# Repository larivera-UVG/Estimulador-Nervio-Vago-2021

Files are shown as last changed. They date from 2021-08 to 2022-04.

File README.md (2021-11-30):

# Estimulador-Nervio-Vago-2021
Desarrollo de un módulo de estimulación para el nervio vago, y su varilla de programación. En este repositorio se encuentran la combinacion de todos los avances logrados en la Fase III del desarollo de un prototipo de estimulador de nervio vago de la Universidad del Valle de Guatemala. Los aportes estan basados en el trabajo de las fases pasadas del proyecto. En esta fase se logro establecer la comunicacion inalambrica de los dos modulos que conforman el estimulador VNS. Ademas se hicieron estudios para determinar el material de desarollo para la carcasa del modulo estimulador, asi como un estudio para validar los parametros de descarga del mismo. Asi mismo se hicieron mejoras a ambos modulos por medio de diseno 3D y diseno de circuitos impresos. 
## Modulo Estimulador
Este es el primero de los dos modulos que conforman el sistema de estimualcion VNS. Este modulo es el encargado de generar la estimulacion electrica responsable de administrar el tratamiento. Es un modulo de 3cm de diametro, conformado completamente por componentes SMD a medida de reducir su tamano.
### Funcionamiento
El modulo estimulador es un circuito digital que consiste de 3 partes clave. Primero se tiene como microcontrolador un ATSAMD21E18-MU para ser usado y programado como un _Trinket M0_. Luego tenemos tenemos un regulador de voltaje que convierte la entrada de 5 V a una salida de 3.3 V. Luego se tiene un convertidor de voltaje a corriente XTR 111 que se encarga de tomar la senal PWM que producida por el ATSAMD21E18, y transforma los pulsos de voltaje a su equivalente en corriente por medio de un espejo de corriente que utiliza de manera externa un circuito con un MOSFET para regular la salida. Para poder alimentar la fuente de corriete que se genera apartir del convertidor de voltaje a corriente se tiene un circuito elevador de voltaje por medio de un LM2622 que opera a 600 kHz. Este provee la alimentacion de 7 volts que es necesaria para activar el convertidor de voltaje a corriente. or ultimo se tiene un Mini-NRF24L01 que se encarga de recibir los parametros de estimulacion enviador por medio de la varilla programadora.
### Codigos
Los codigos utilizados para el modulo estimulador se dividen en 2 partes. Una serie de codigos para pruebas directamente con los breakout boards (Trinket M0) y los modulos de comunicacion RF (NRF24L01). Los demas codigos son los codigos encargados de generar los pulsos PWM con una rampa de inicio y una rampa de bajada desarollados por Gustavo Ordoñez, en conjunto con la seccion de codigo encargada de generar la comunicacion por medio de RF por medio de la funcion __RFBegin__ y la funcion __RFSetup__.
#### Codigos Para Pruebas de Comunicacion
De los codigos para pruebas se tienen los siguientes archivos:
* Codigos_de_Diagnostico_para_los_modulos: Este codigo imprime en la consola (COM) los parametros de transmision del modulo NRF24L01 e indica si este tiene problemas de transmision:
* Pruebas basicas de diagnostico:
  * Trinket_reciver: Esta es un prueba donde el ESP8266/ESP Wroom32 mandan una serie de caracteres y en este codigo el trinket recibe los caracteres y los muestra en la interfaz serial
  * SAMD_a_ESP8266_nRF24L01: Este es una version con mas modos de prueba que el codigo anterior. Por medio de 5 _cases_ se puede probar mandar, recibir, mandar y rebir datos de el trinket a otro microcontrolador con el modulo nEF24L01 y los _addresses_ indicados
  * Slave_NRF_tester: Un codigo que prueba mandar una serie de numeros que incrementan de manera lineal. Aqui el receptor no reporta nada, solo el emisor reporta si el envio fue exitoso o no
  * Pruebas_con_el_ESP32: Codigo de pruebas para ver si se podian recibir los datos desde el ESP Wroom 32
#### Codigo del modulo estimulador
Aqui solo se tiene un archivo de codigo comentado que es la combinacion del codigo de Gustavo y mi codigo. Este es el codigo que se le debe de cargar al modulo estimulador para poder lograr la comunicacion RF y la generacion de Pulsos
* PWM_Module_With_RF
### Modelos CAD
*De momento todavia no hay archivos cad para la carcaza del estimulador*
#### Archivos de Inventor 2021
Para poder acesar a los archivos de inventor en conjunto con las librerias de componentes, dadas las limitaciones de tamano de 100 MB para un repositorio de Github, estas se van a colocar como un archivo de texto (.txt) que contiene el link al Google Drive donde estan subidos y distribuidos por carpetas
Tambien adjunto el link aqui: 
#### STLs
Los archivos que se obtienen apartir del programa CAD, en este caso Inventor 2021, para ser introducidos al _slicer_ (software encargado de traducir el STL a codigo que puede ser interpretado por la impresora) que en torno genera G-code. Se recomendaria utilizar estos archivos para impresion de la carcasa, ya que al utilizar directamtente el G-code, puede que este no este optimizado para impresora donde se quiere imprimir.
#### G-Code
El G-Code fue generado utilizando el _slicer_ de Ultimaker, Ultimaker Cura Version 4.7. Se optimizo para poderse imprimir con una Ender 3 V1 y utilizando filamento PLA+. Es importante notar que la temperatura de impresion del PLA+ es superior a la del PLA normal. Tambien se optimizaron los comandos para reducir el _stringing_ y otros fenomenos del filamento. Se hiceron impresiones con PLA+ azul oscuro de eSUN y PLA+ cobre _silky_ tambien de eSUN. Los resultados de impresion con otros filamentos y en otras impresoras pueden ser diferentes. Sin embargo, las impresiones estan siempre puestas en el centro de la cama de impresion. La ender 3 V2 tiene un volumen de impresion de 25x25x30 cm.
### Pruebas de Neuro Estimulacion
#### Archivo de LTspice
Este archivo contiene los circuitos con los parametros de simulacion adecuados para validar los resultados teoricos
* Simulacion Nervio Vago.asc: Archivo para ser abierto en LTspice con los circuitos y parametros
* Simulacion Nervio Vago.raw: Archivo que contiene los parametros para replicar las graficas
* Simulacion Nervio Vago.plt
* Simulacion Nervio Vago.log
## Modulo Programador
### Codigos
Los codigos utilizados para la varilla programadora se dividen en 3 partes. Al igual que el modulo estimulador se tienen codigos para pruebas de comunicacion por medio del modulo NRF24L01. Luego se tiene el codigo principal que le da funcionalidad WiFi y RF a la varilla programadora. Por ultimo esta el codigo de la interfaz grafica que le deja al usuario programar los parametros por medio de una consola corriendo una aplicacion de Python.
### Codigo de la varilla programadora
* Compu_a_Esp_a_SAMD21: Este codigo
### Codigo para la interfaz grafica
* Interfaz_VNS.py
### Codigo para pruebas de comunicacion
* Codigos de Diagnostico
 * I2C_Scanner: Da la direccion de cualquier dispositivo conectado por medio de I2C a el ESP8266
 * lcd_i2c-test: Pruebas para verificar que los datos mandados por I2C aparezcan en la pantalla LCD 1602
 * Master_NRF_Tester: Codigo hermano del Slave_NRF_tester que muestra en la pantalla serial si se estan recibiendo exitosamente una serie de numeros incrementales, si no es el caso avisa que hubo un error de comunicacion de la forma "TX Failed"
*  ESP8266_a_SAMD21_nRF4L01: Codigo hermano de SAMD_a_ESP8266_nRF24L01 que se utiliza para hacer pruebas de emision, recepcion, emision y recepcion e inclusive pruebas de la pantalla LCD por medio de I2C para el ESP8266 y el ESP Wroom32
*  Trinket_Como_Receptor_de_los_Parametros: Codigo de Pruebas basicas para recibir datos en forma de un array desde el Arduino o desde el ESP8266
### Modelos CAD 
Misma descripcion que para el modulo estimulador, pero se van a dar dos links diferentes a la misma carpeta de Google Drive para facilitar el orden.
#### Archivos de Inventor 2021
Para poder acesar a los archivos de inventor en conjunto con las librerias de componentes, dadas las limitaciones de tamano de 100 MB para un repositorio de Github, estas se van a colocar como un archivo de texto (.txt) que contiene el link al Google Drive donde estan subidos y distribuidos por carpetas
Tambien adjunto el link aqui: 
#### STLs
Los archivos que se obtienen apartir del programa CAD, en este caso Inventor 2021, para ser introducidos al _slicer_ (software encargado de traducir el STL a codigo que puede ser interpretado por la impresora) que en torno genera G-code. Se recomendaria utilizar estos archivos para impresion de la carcasa, ya que al utilizar directamtente el G-code, puede que este no este optimizado para impresora donde se quiere imprimir.
#### G-Code
El G-Code fue generado utilizando el _slicer_ de Ultimaker, Ultimaker Cura Version 4.7. Se optimizo para poderse imprimir con una Ender 3 V1 y utilizando filamento PLA+. Es importante notar que la temperatura de impresion del PLA+ es superior a la del PLA normal. Tambien se optimizaron los comandos para reducir el _stringing_ y otros fenomenos del filamento. Se hiceron impresiones con PLA+ azul oscuro de eSUN y PLA+ cobre _silky_ tambien de eSUN. Los resultados de impresion con otros filamentos y en otras impresoras pueden ser diferentes. Sin embargo, las impresiones estan siempre puestas en el centro de la cama de impresion. La ender 3 V2 tiene un volumen de impresion de 25x25x30 cm.
## Open OCD
En esta carpeta estan tanto los archivos de Altium asi como los Gerbers necesarios para la fabricacion de la placa que se uso para cargar el _bootloader_ al SAMD21E18-AF. 
Se utilizaron los siguientes links para poder cargar OpenOCD en una Rapberry Pi 3B+ y generar el archivo .hex que contiene el bootloader del arduino zero y el uf2 para el trinket M0:
* [Link para adaptar un Trinket M0 a un Nintendo Switch](http://www.google.fr/ "Named link title")
* [Video de como instalar OpenOCD en la RaspberryPi y cargar el archivo .hex](http://www.google.fr/ "Named link title")
* [Tutorial de Adafruit de como usar OpenOcd](http://www.google.fr/ "Named link title")
## Estudio de Mercado para La bio-compatibilidad
Este estudio esta presentado en un archivo de Microsoft Excel .xlxs y tiene diversas partes. Una parte del estudio encuadra el listado de los 8 materiales y por medio de tres fuentes de lugares diferentes (locales de ser posible) determina el precio/g del material. Otra parte esta donde se indican las caracteristicas a ser comparadas a mayor detalle. Tambien hay un recuadro donde se catalogan las propiedades mecanicas relevantes a la ergonomia y fabricacion de los materiales. Otra seccion explica los criterios de biocompatibilidad y explica porque se determino que el material tenia que ser bio-inerte. Por ultimo se tiene el recuadro donde se ejemplifica el estudio de mercado con los resultados para cada material
## Documentacion
### Excel con el resumen de todas las corridas de las pruebas de simulacion de nervio vago
Este archivo contiene la compilacion de las diferentes corridas con las medidas en los nodos mas importantes. Se tienen 4 paginas, una para la corrida de un solo nodo (extension de 1cm de tejido) y la otra con 5 nodos (extension de 6 cm de tejido) ademas de una pagina donde se realizaron pruebas transitorias y otra donde se deriva el despeje matematico del circuito

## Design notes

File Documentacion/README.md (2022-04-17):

# Documentacion
## Detalles:
En la documentacion se encuentran los archivos y articulos relevantes que se pueden utulizar para derivar los resultados a los que se llegaron en la tesis , en la documentacion contamos con los siguientes archivos:
### 2.1 Trade_Studies_Module...
Este archivo contiene la metodologia de space systems engineering de la NASA para desarollar un Estudio de Mercado como el que utilizo en la investigacion de bio-compatibilidad
### Articulo Cientifico Rodrigo Figueroa
Este documento contiene el articulo cientifico donde se detalla de manera breve los avances en el desarollo del sistema de intercomunicaicon y los dos estudios, el de biocompatibilidad y el estudio del modelo del nervio vago

### Copia de Presentacion de....
Este archivo contiene la presentacion en formato PDF que se utilizo en la defensa de terna de esta tesis

### Guia_para_La_instalacion:
Es un documento corto que detalla los pasos necesarios para poder descargadr todas las librerias necesarias para correr el dispositivo.

### Protocolo_2021_Rodrigo...
Aqui esta el protocolo presentado en la primera mitad del ano 2021 que detallaba los pasos a seguir en el desarollo de la tesis
### Pruebas Teoricas de descarga....
Este documento .xl contiene el documento donde se detallan los resultados de las pruebas de simulacion realizados atraves de LTSpice para validar el modelo del nervio vago

### Tesis_2021__Rodrigo...
Este documento contiene la version de la tesis que se presento a finales de Diciembre de 2021 sin ser editado por el comite de estilo y redaccion de la UVG

### Trade Study-Biomateriales: 
Este documento contiene los resultados del estudio de biocompatibilidad que se explican en la tesis.

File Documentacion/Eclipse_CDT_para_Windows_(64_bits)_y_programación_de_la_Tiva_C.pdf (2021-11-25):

Universidad Del Valle de Guatemala
Departamento de Ingeniería Electrónica, Mecatrónica y Biomédica
Luis Alberto Rivera

## Instalación de Eclipse CDT, GNU ARM Embedded Toolchain y TivaWare C para Windows 10 (64 bits)

Desarrollo de Programas para la Tiva C

Eclipse y MinGW

La instalación de Eclipse y MinGW se ilustra en el siguiente vídeo. Abajo se dan los enlaces para descargar los paquetes y se dan instrucciones adicionales. https://www.youtube.com/watch?v=WRYHKNVV5H0

Instalador de Eclipse (eclipse-inst-win64.exe): https://www.eclipse.org/downloads/packages/installer
Nota: Correr el ejecutable puede tardar un poco.
Aparecerá una ventana para seleccionar el IDE específico que desea. Seleccione el “Eclipse IDE for C/C++ Developers”.

Instalar GCC (MinGW64): Esto permite compilar programas en C/C++ para Windows.
Descargue el ejecutable | MinGW-W64-install.exe (https://sourceforge.net/projects/mingw-w64/files/Toolchains%20targetting%20Win32/Personal%20Builds/mingw-builds/installer/mingw-w64-install.exe) | (no el .zip) de
https://sourceforge.net/projects/mingw-w64/files/mingw-w64/
Al correr el instalador, en la ventana de Settings, posiblemente necesite cambiar la opción de “Architecture” a x86_64. Vea el vídeo indicado arriba (minuto 6:14). En la opción de versión, deje la versión más reciente.

Agregar gcc/g++ de MinGW al “System Path”: Esto es para que Eclipse detecte a MinGW GCC automáticamente, y para poder compilar directamente desde una terminal fuera de Eclipse.
Siga las instrucciones de la página web siguiente, a partir del paso #12: http://www.codebind.com/cprogramming/install-mingw-windows-10-gcc/

Nota: Probablemente la ruta que deba agregar sea distinta a la mostrada en la página web anterior. Allí se muestra “C:\MinGW\bin”, pero es probable que la ruta sea algo como “C:\Program Files\mingw-w64\x86_64-8.1.0-posix-seh-rt_v6-rev0\mingw64\bin”.

En la figura siguiente se muestra la ventana en la que debe agregar la ruta. Note que puede buscar el respectivo folder con el botón “Browse…”.

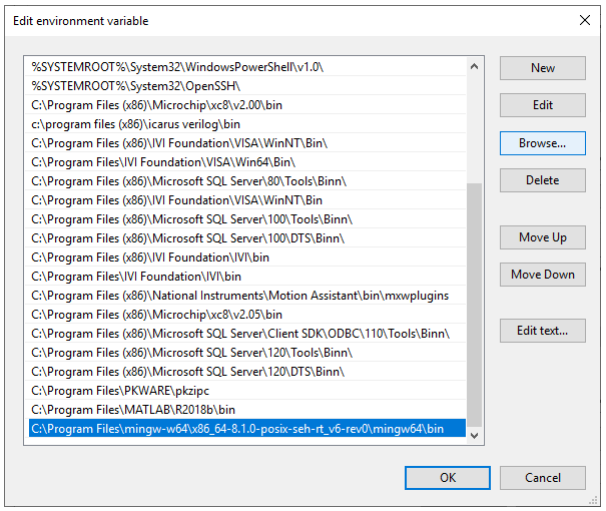
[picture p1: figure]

Para verificar que todo está bien, pruebe crear un programa “Hello World”, compilarlo y correrlo en Eclipse. Luego, pruebe correr el programa compilado en Eclipse en una terminal externa a Eclipse (Command Prompt y/o Windows PowerShell). Finalmente, pruebe compilar el programa directamente desde la terminal externa usando gcc. Corra el programa. Todo esto se ilustra en el documento “Eclipse Hello World.pdf”.

LM Flash Programmer, TivaWare C y GNU ARM Embedded Toolchain

Descargue e instale el LM Flash Programmer (LMFlashProgrammer.msi): http://www.ti.com/tool/LMFLASHPROGRAMMER
Necesitará registrarse. El usuario creado de Texas Instruments le servirá para éste y otros productos.

Descargue e instale el TivaWare C para los controladores de la serie TM4C (SW-TM4C-2.1.4.178.exe):
http://software-dl.ti.com/tiva-c/SW-TM4C/latest/index_FDS.html
Puede ingresar con el mismo usuario creado anteriormente.

Instale el GNU ARM Embedded Toolchain (arm-none-eabi):
(descargue el .exe de la versión más reciente para Windows; no importa que diga 32 bits) https://developer.arm.com/tools-and-software/open-source-software/developer-tools/gnu-toolchain/gnu-rm/downloads (https://developer.arm.com/tools-and-software/open-source-software/developer-tools/gnu-toolchain/gnu-rm/downloads)

IMPORTANTE: Antes de terminar la instalación, marque la casilla “Add path to environment variable”, si ésta no está marcada por defecto.

Al parecer, en C:\Program Files (x86)\GNU Tools Arm Embedded\9 2019-q4-major\bin no está el ejecutable make.exe, necesario a la hora de compilar. Se puede usar el make.exe que trae MinGW64. Siga los siguientes pasos:

Vaya a: C:\Program Files\mingw-w64\x86_64-8.1.0-posix-seh-rt_v6-rev0\mingw64\bin Debería ver el ejecutable “mingw32-make.exe”. Copie dicho archivo al directorio C:\Program Files (x86)\GNU Tools Arm Embedded\9 2019-q4-major\bin
Finalmente, cámbiele el nombre de “mingw32-make.exe” a “make.exe”.

Nota: las rutas indicadas arriba se asumen por defecto. Éstas pueden diferir, según su instalación de GNU ARM Embedded Toolchain y MinGW.

Desarrollo de Programas para la Tiva C en Eclipse:

Abra Eclipse y seleccione el workspace en que se desee trabajar.

Cree un proyecto nuevo: en el menú principal, File > New > C/C+ Project. En la ventana que aparece, seleccione la opción “C Managed Build”.

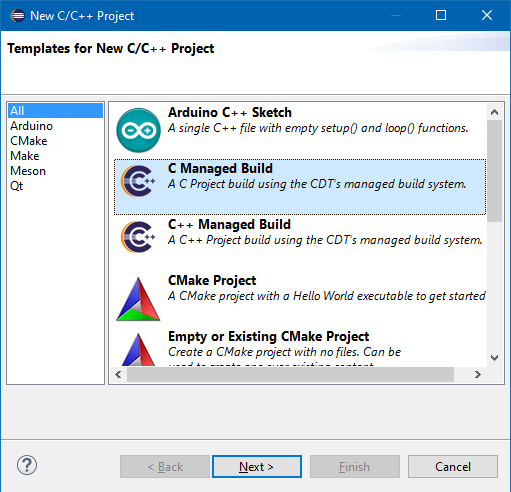
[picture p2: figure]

Seleccione el tipo de proyecto “Empty Project” y el toolchain “Cross GCC”. Dé un nombre al proyecto en el espacio correspondiente.

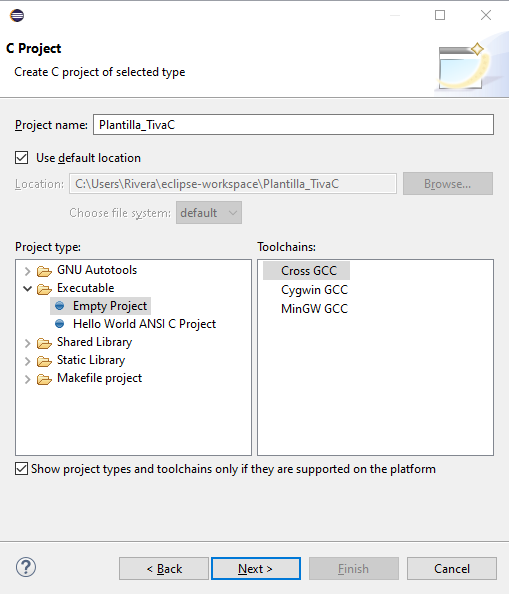
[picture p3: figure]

En la ventana “Select Configurations”, remueva el cheque en el cuadro “Debug”, dejando únicamente la opción de “Release”. Dele click en “Finish”.
Nota 1: se pueden dejar las dos opciones, pero se deberá tener mucho cuidado para las configuraciones que se describen más adelante. También se puede dejar únicamente la opción “Debug”, si se desea usar el debugger de Eclipse.
Nota 2: En “Advanced settings” se pueden hacer las configuraciones que se describen a continuación, de una vez. Dichas configuraciones se pueden hacer después de crear el proyecto, como se explica abajo.

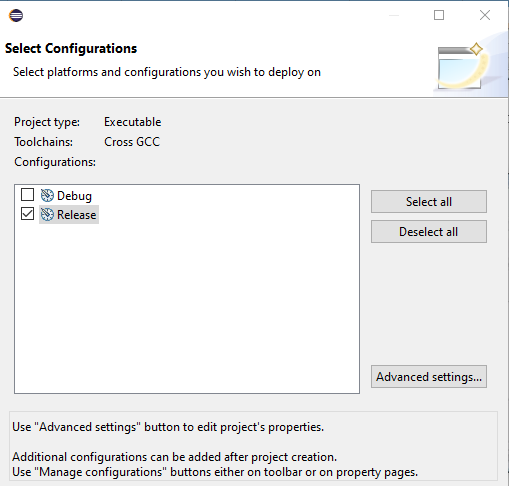
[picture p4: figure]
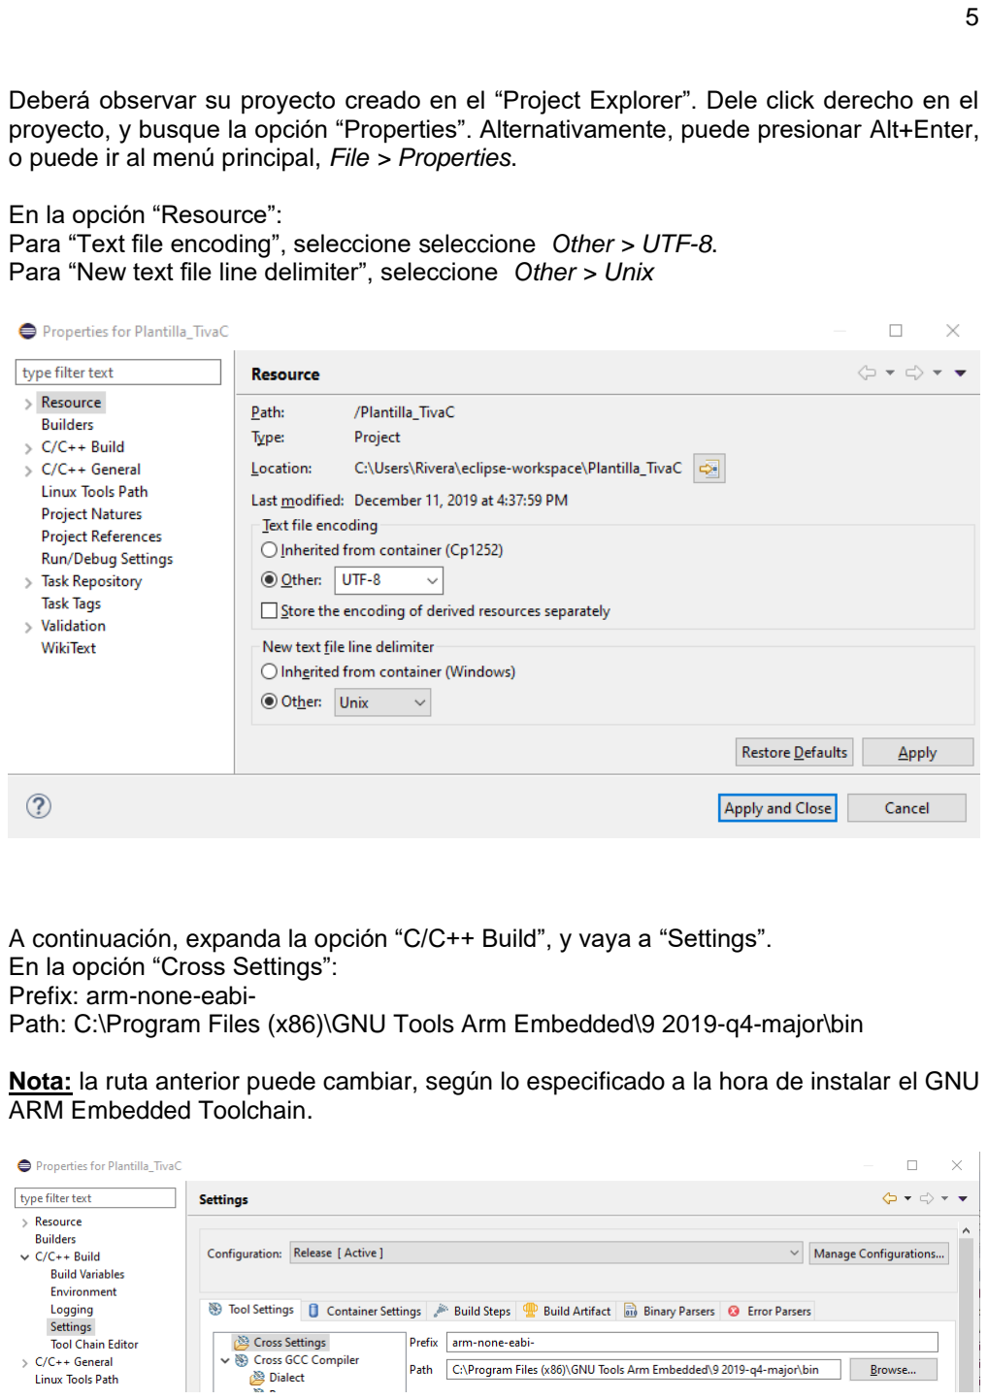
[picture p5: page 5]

Deberá observar su proyecto creado en el “Project Explorer”. Dele click derecho en el proyecto, y busque la opción “Properties”. Alternativamente, puede presionar Alt+Enter, o puede ir al menú principal, File > Properties.

En la opción “Resource”:
Para “Text file encoding”, seleccione seleccione Other > UTF-8.
Para “New text file line delimiter”, seleccione Other > Unix

A continuación, expanda la opción “C/C++ Build”, y vaya a “Settings”.
En la opción “Cross Settings”:
Prefix: arm-none-eabi-Path: C:\Program Files (x86)\GNU Tools Arm Embedded\9 2019-q4-major\bin

Nota: la ruta anterior puede cambiar, según lo especificado a la hora de instalar el GNU ARM Embedded Toolchain.

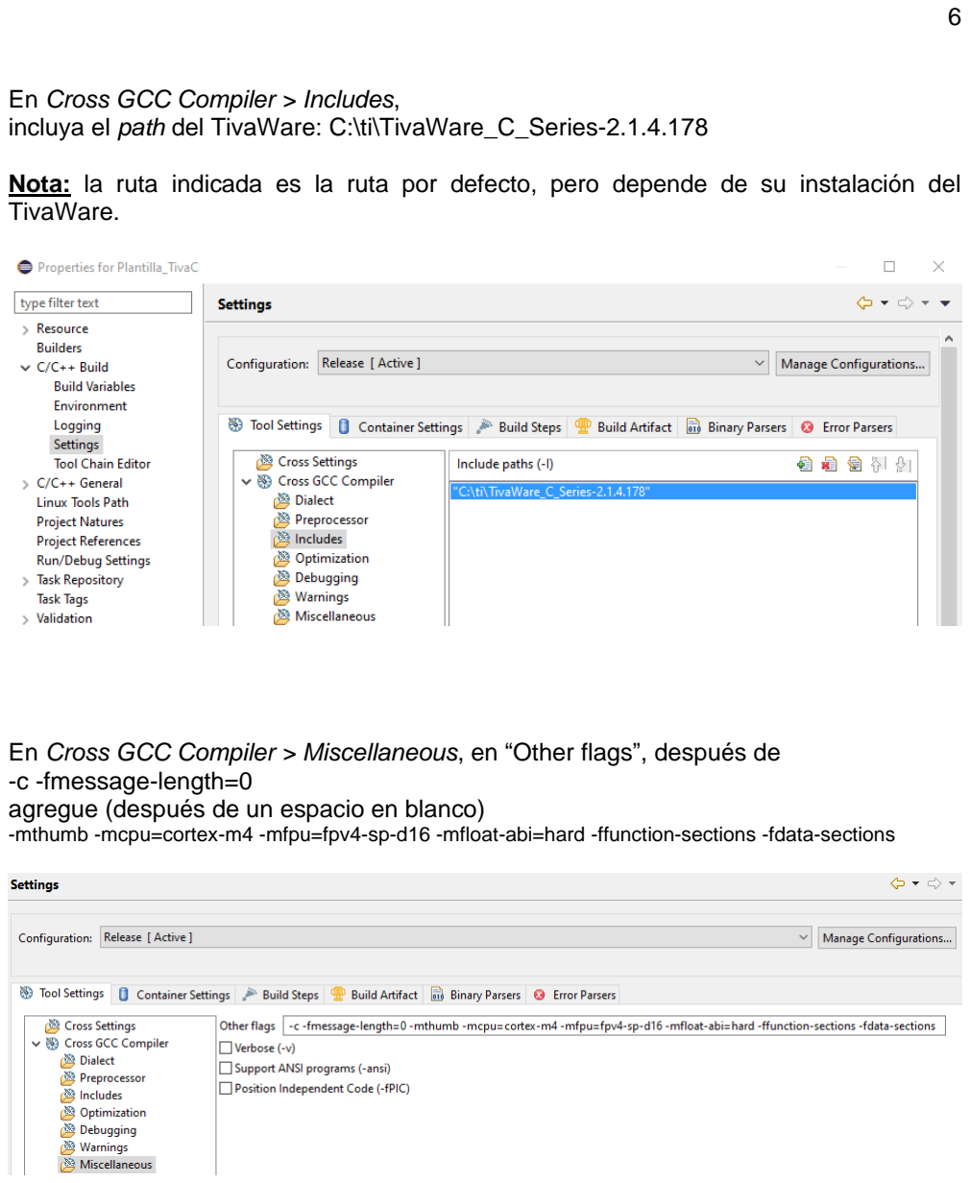
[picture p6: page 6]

En Cross GCC Compiler > Includes,
incluya el path del TivaWare: C:\ti\TivaWare_C_Series-2.1.4.178

Nota: la ruta indicada es la ruta por defecto, pero depende de su instalación del TivaWare.

En Cross GCC Compiler > Miscellaneous, en “Other flags”, después de
-c -fmessage-length=0
agregue (después de un espacio en blanco)
-mthumb -mcpu=cortex-m4 -mfpu=fpv4-sp-d16 -mfloat-abi=hard -ffunction-sections -fdata-sections

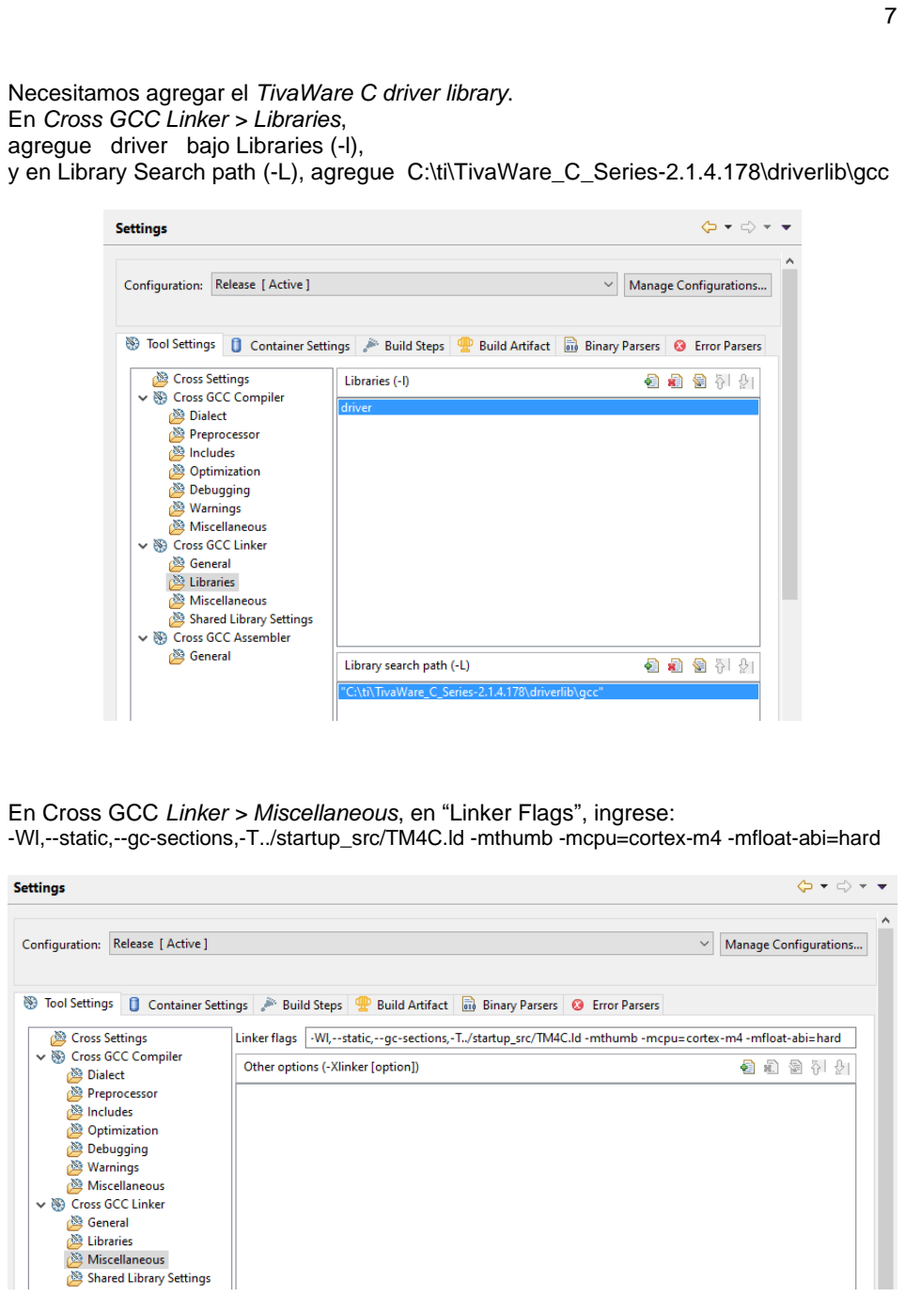
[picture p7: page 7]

Necesitamos agregar el TivaWare C driver library.
En Cross GCC Linker > Libraries,
agregue driver bajo Libraries (-l),
y en Library Search path (-L), agregue C:\ti\TivaWare_C_Series-2.1.4.178\driverlib\gcc

En Cross GCC Linker > Miscellaneous, en “Linker Flags”, ingrese: -Wl,--static,--gc-sections,-T../startup_src/TM4C.ld -mthumb -mcpu=cortex-m4 -mfloat-abi=hard

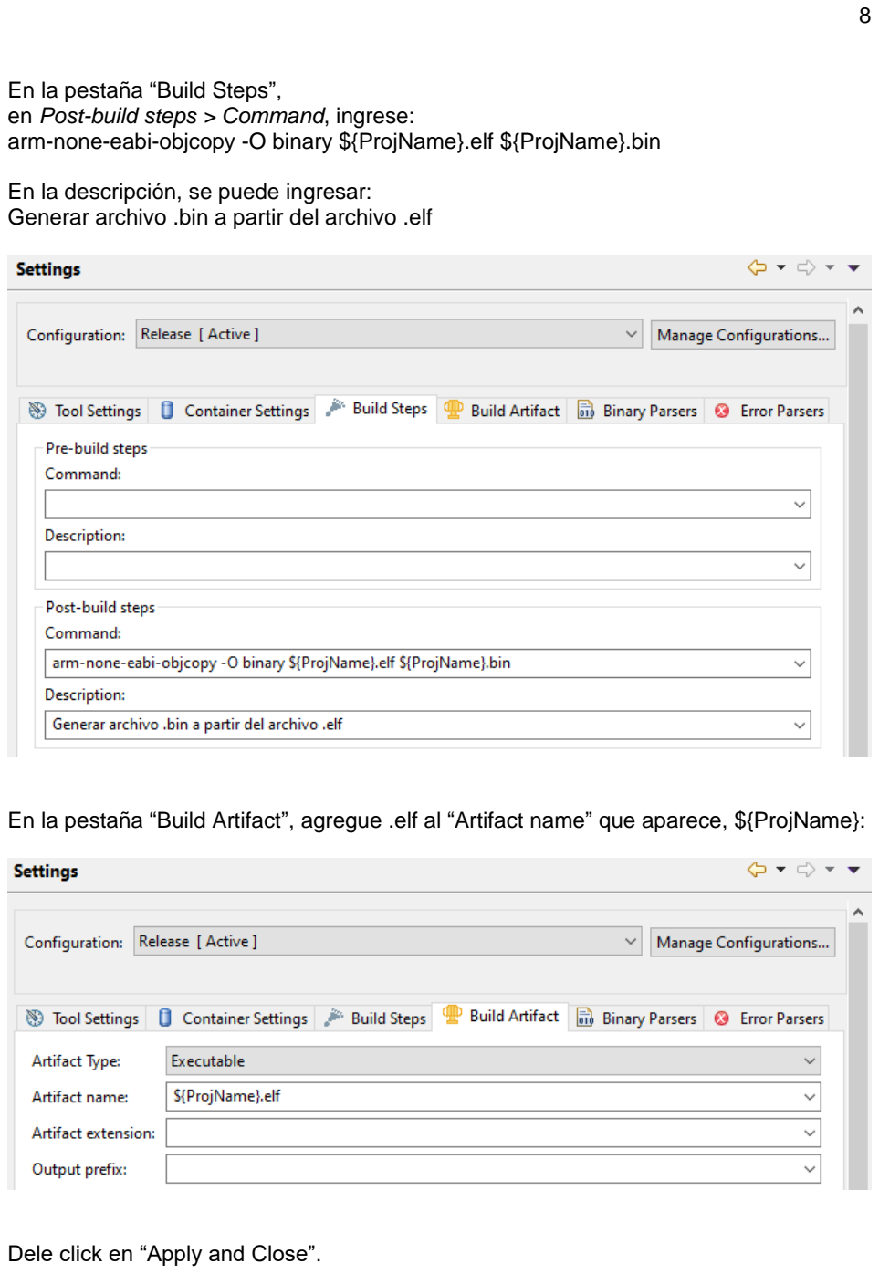
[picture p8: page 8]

En la pestaña “Build Steps”,
en Post-build steps > Command, ingrese:
arm-none-eabi-objcopy -O binary ${ProjName}.elf ${ProjName}.bin

En la descripción, se puede ingresar:
Generar archivo .bin a partir del archivo .elf

En la pestaña “Build Artifact”, agregue .elf al “Artifact name” que aparece, ${ProjName}:

Dele click en “Apply and Close”.

Ahora necesitamos agregar archivos fuente al proyecto.
En primer lugar, descargue el folder “startup_src” que se encuentre en Canvas. Copie el folder “startup_src” al folder de su proyecto en el “Project Explorer” de Eclipse. “startup_src” tiene dos archivos, TM4C_startup.c, y TM4C.ld, los cuales tienen definiciones y declaraciones necesarias para inicializar su programa.

Finalmente, se debe agregar el archivo con su programa. Como ejemplo, copie el archivo blinky.c (también en Canvas). Este programa configura un LED de la Tiva C y lo enciende y apaga constantemente.

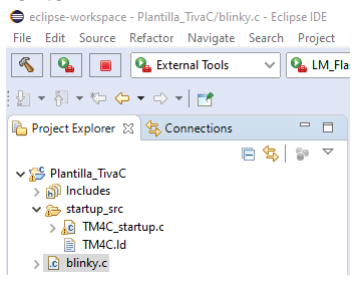
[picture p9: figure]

Con todo lo anterior, ya está listo para compilar su programa. Para compilar, busque el ícono de build (un martillo). Alternativamente, puede ir al menú principal y buscar Project > Build Project.
Si todo está bien, al compilar no aparecerán mensajes de error en la consola, y en el folder de su proyecto aparecerá el folder “Release” (y/o “Debug”, según la configuración de su proyecto). En “Release”, verá varios archivos, incluido un .bin. El archivo .bin es el que se cargará a la Tiva C, como se explica más adelante.

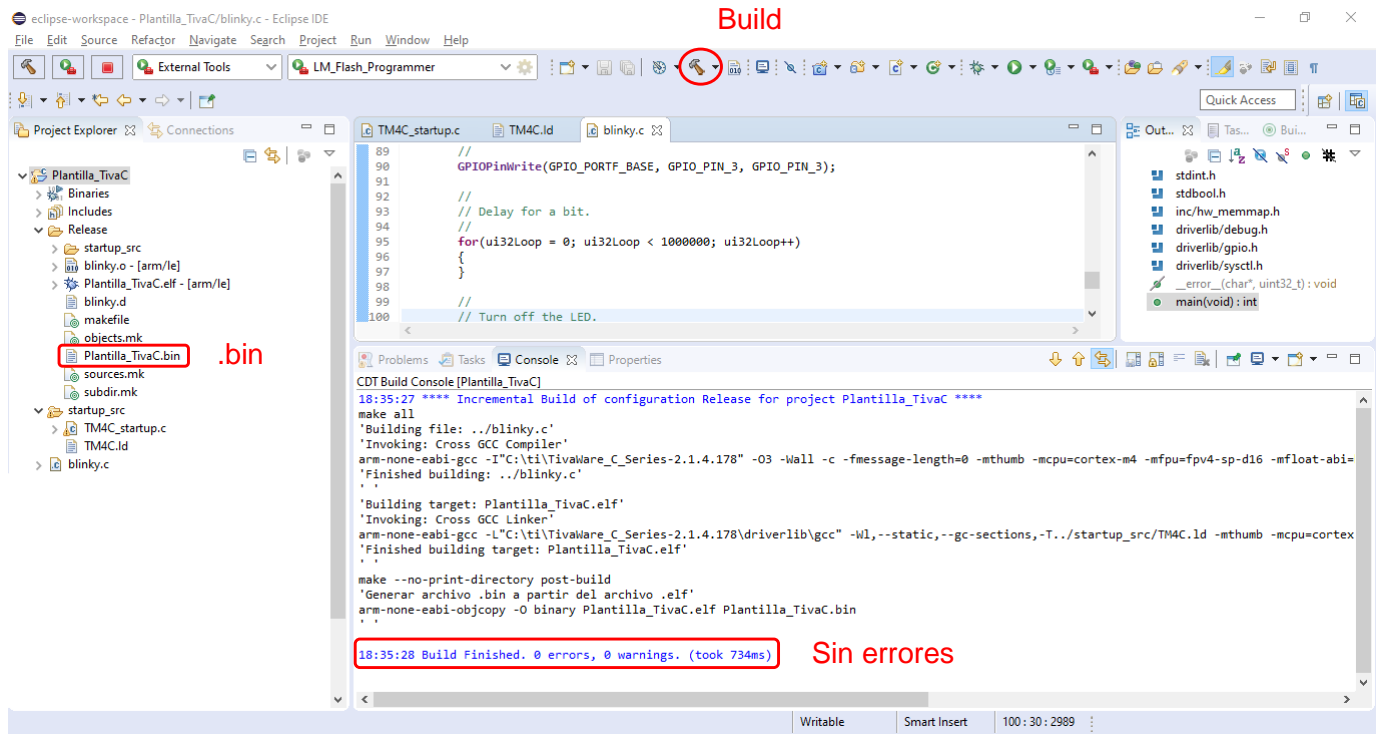
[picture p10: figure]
Build; .bin; Sin errores

Para futuros programas, puede crear proyectos en blanco e importar archivos y configuraciones desde el proyecto anterior. Así, sólo deberá reemplazar/agregar los archivos .c. No necesitará hacer todas las configuraciones nuevamente.

Para programar la Tiva C

Usando LM Flash Programmer directamente
Abra el programa.
En la pestaña “Program”, busque el archivo .bin generado en Eclipse. Se recomienda seleccionar la opción “Reset MCU After Program” (si no, deberá presionar el botón de Reset de la Tiva luego de programar, para que el programa empiece a ejecutar).
Dele click en el botón “Program”.

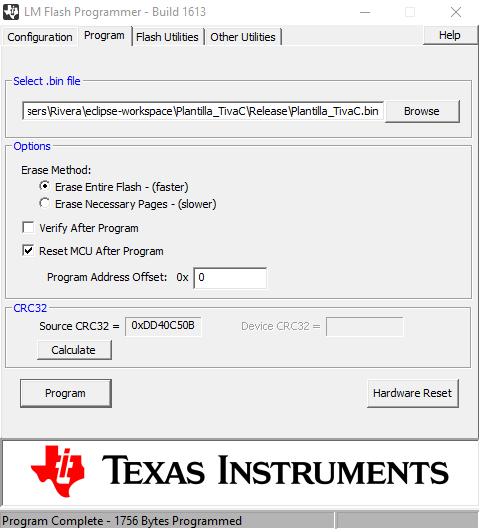
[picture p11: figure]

Usando LM Flash Programmer desde Eclipse
Vaya al menú de Eclipse en la parte superior. Busque Run > External Tools > External Tools Configurations.
Dele click en “New launch configuration”
Nombre la configuración (se sugiere LM_Flash_Programmer)
Busque la ubicación del LMFlash.exe y colóquela en “Location”.
En “Working Directory”, busque el directorio donde se encuentra el archivo .bin que se desea quemar en la Tiva.
En “Arguments”, coloque: ${project_name}.bin

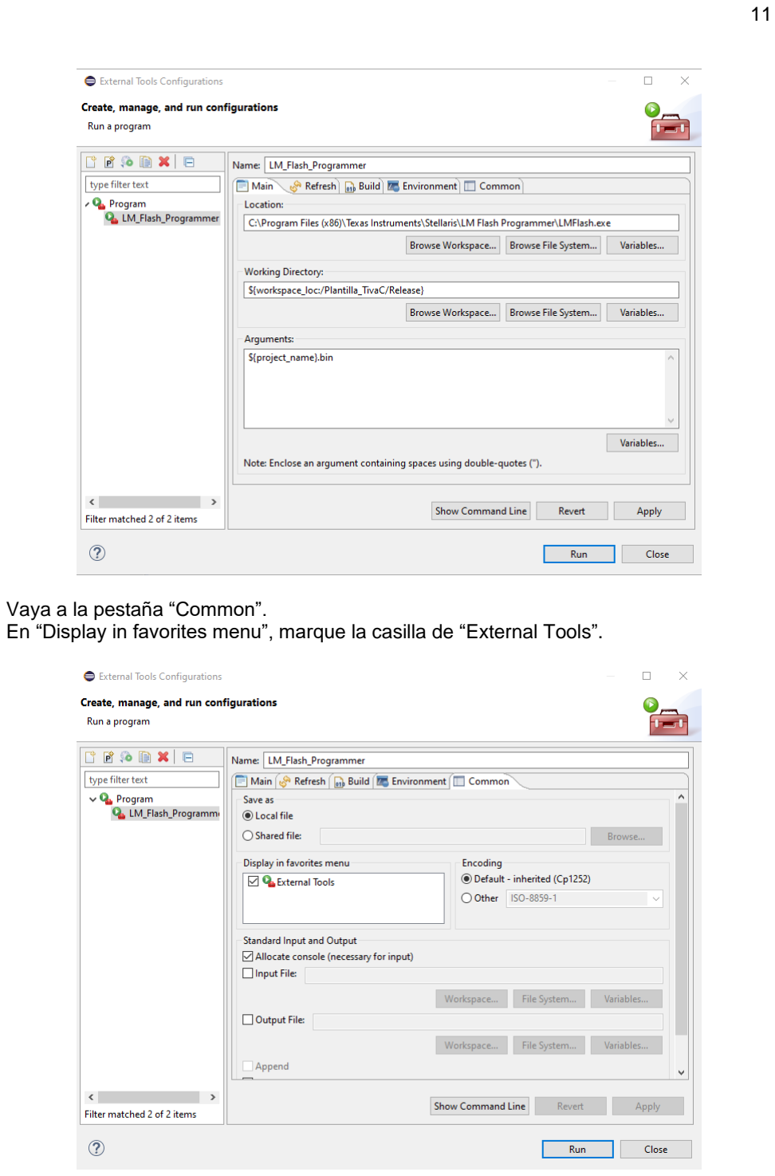
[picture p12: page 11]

Vaya a la pestaña “Common”.
En “Display in favorites menu”, marque la casilla de “External Tools”.

La próxima vez que se seleccione Run > External Tools > LM_Flash_Programmer o se presione el ícono de “Run LM_Flash_Programmer”, se compilará el programa y se cargará a la Tiva de una vez.

Importante: Luego de cargar el programa, deberá presionar el botón de Reset de la Tiva para que empiece a ejecutar.

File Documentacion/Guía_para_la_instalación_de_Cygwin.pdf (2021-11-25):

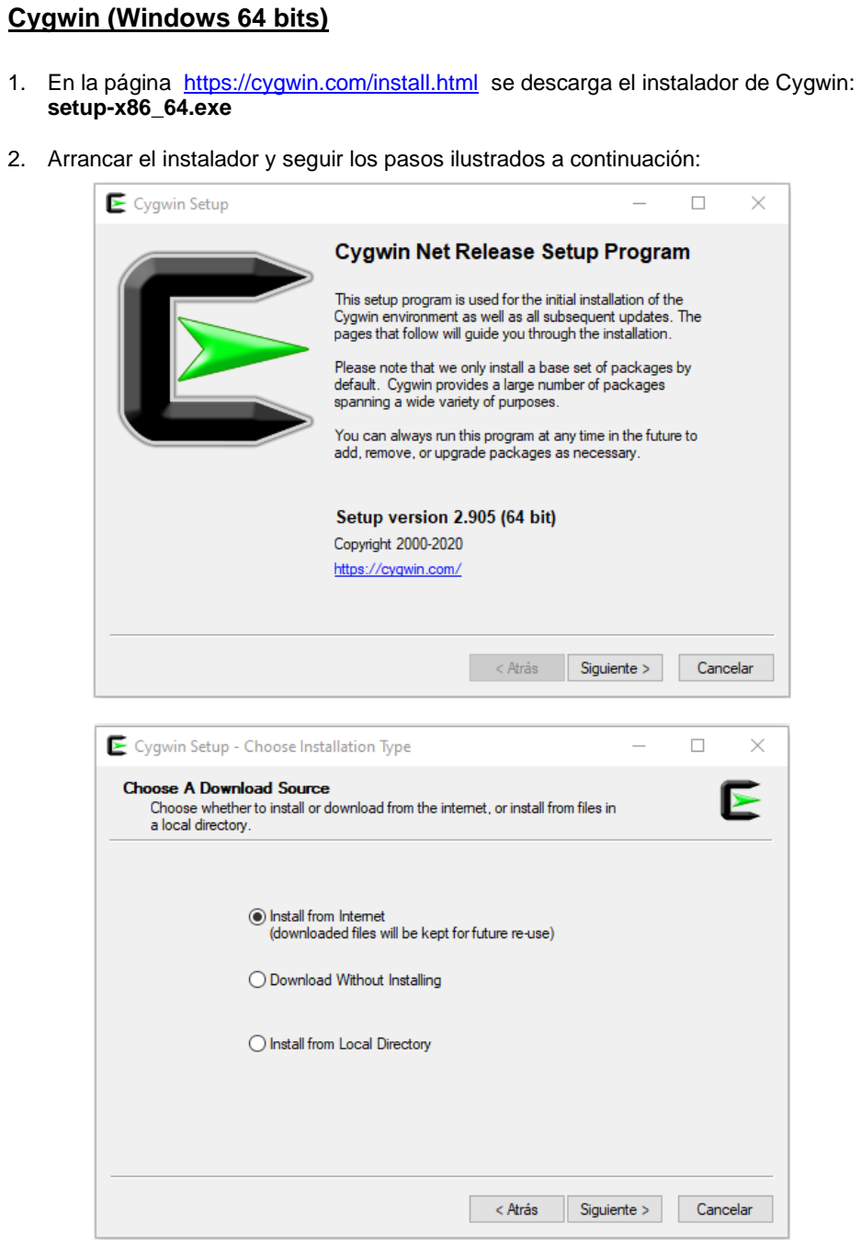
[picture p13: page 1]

Cygwin (Windows 64 bits)

1. En la página https://cygwin.com/install.html se descarga el instalador de Cygwin: setup-x86_64.exe
2. Arrancar el instalador y seguir los pasos ilustrados a continuación:

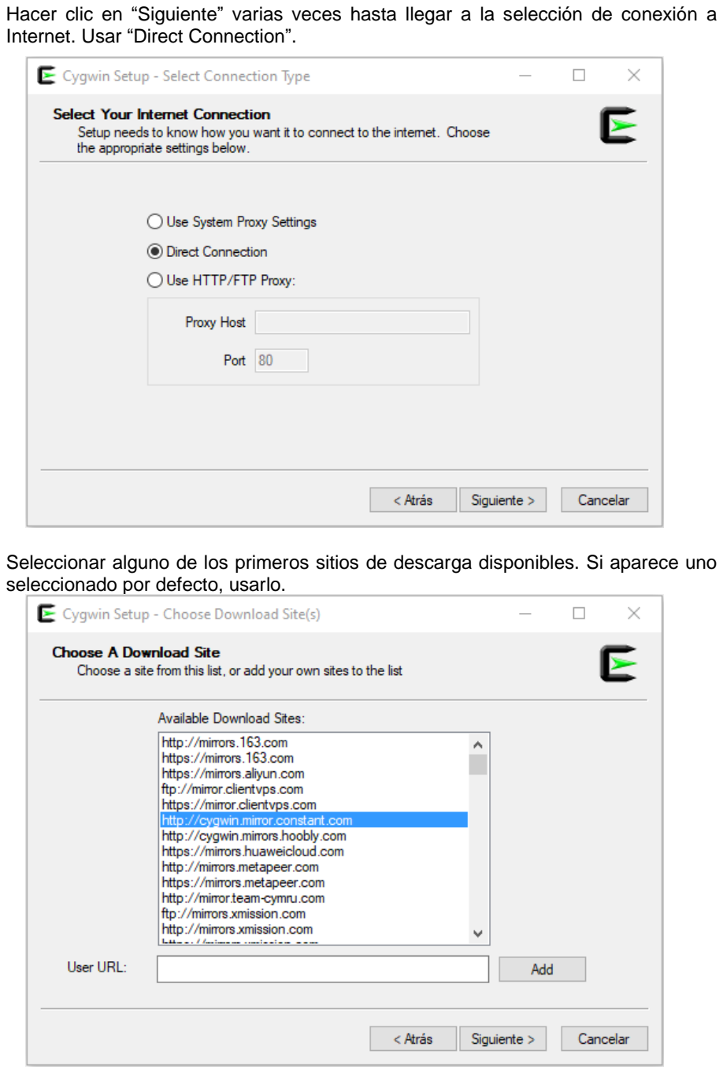
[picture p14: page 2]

Hacer clic en “Siguiente” varias veces hasta llegar a la selección de conexión a Internet. Usar “Direct Connection”.

Seleccionar alguno de los primeros sitios de descarga disponibles. Si aparece uno seleccionado por defecto, usarlo.

Al darle clic a “Siguiente”, luego de unos instantes debe aparecer una ventana para seleccionar los paquetes a instalar. En el menú “View”, seleccionar “Category”. Se deben dejar las opciones por defecto para todos los paquetes, a excepción del paquete “Devel”, el cual debe cambiarse de la opción “Default” a “Install”, como se ve a continuación.

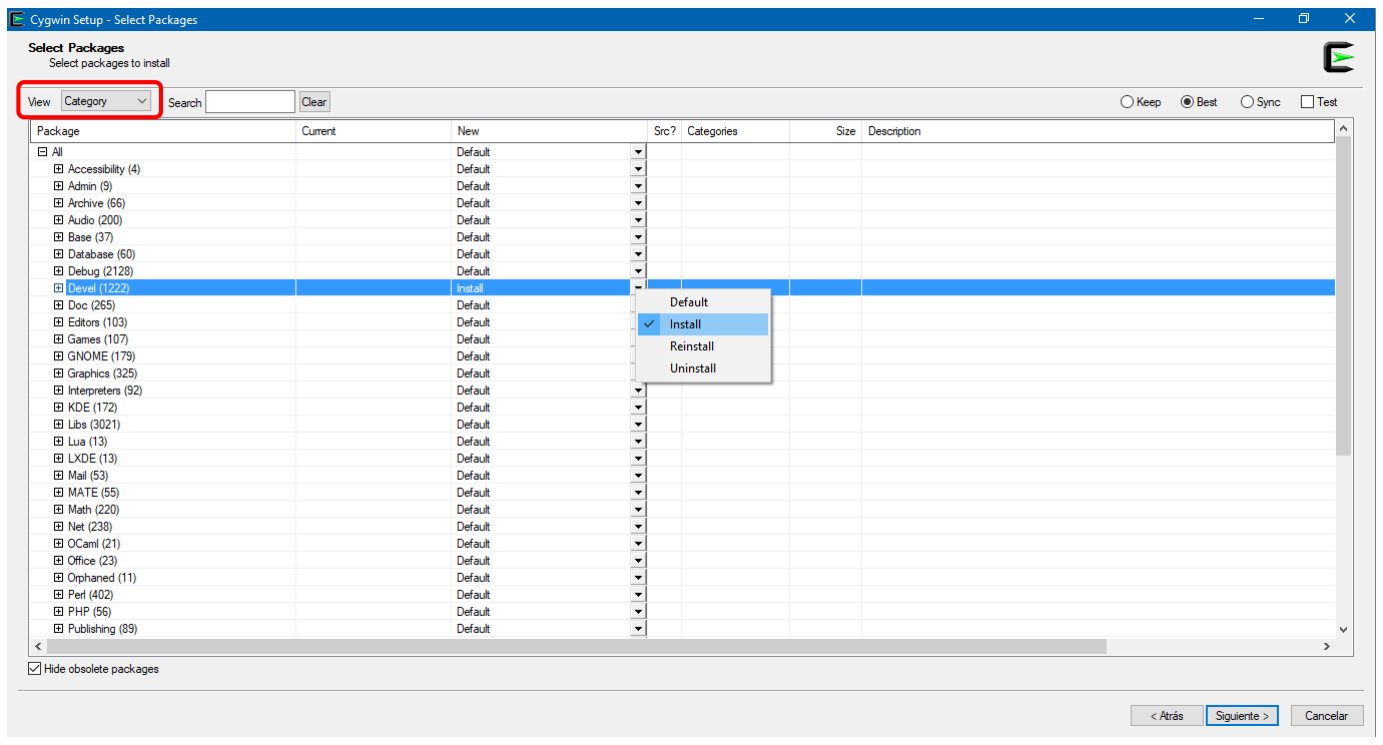
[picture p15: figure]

Si aparece una ventana como la siguiente, mantener marcada la casilla “Accept default problem solutions”.

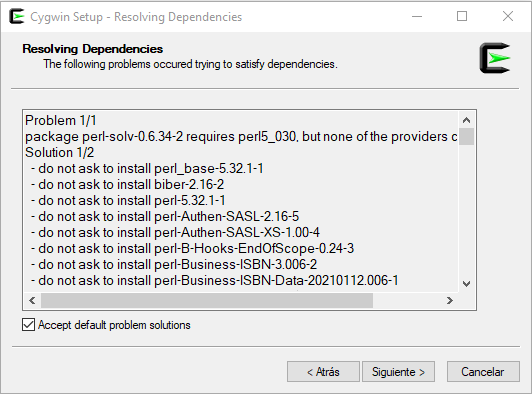
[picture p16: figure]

Dar clic en “Siguiente” en las próximas ventanas, hasta que inicie la instalación.

Importante: esta instalación puede tomar bastante tiempo, especialmente con una conexión a internet inferior a los 10 Mbps.

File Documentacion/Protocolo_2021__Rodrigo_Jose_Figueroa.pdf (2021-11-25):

## UNIVERSIDAD DEL VALLE DE GUATEMALA Facultad de Ingeniería

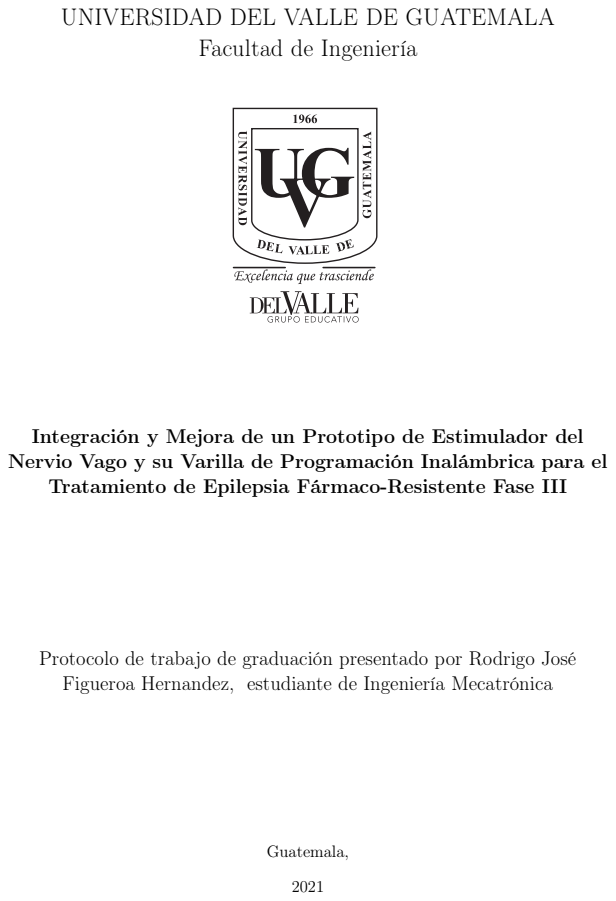
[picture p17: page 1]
Guatemala,

Integración y Mejora de un Prototipo de Estimulador del
Nervio Vago y su Varilla de Programación Inalámbrica para el
Tratamiento de Epilepsia Fármaco-Resistente Fase III

Protocolo de trabajo de graduación presentado por Rodrigo José
Figueroa Hernandez, estudiante de Ingeniería Mecatrónica

### Resumen

El presente protocolo detalla la tercera fase de desarrollo de un proyecto que busca desarrollar un estimulador de nervio vago. Dicho proyecto tiene como enfoque diseñar y desarrollar un dispositivo cuyo objetivo es el tratamiento de la epilepsia farmacorresistente. Mediante una serie de descargas, de amplitud y frecuencia controladas, se busca estimular el nervio vago. Dicha estimulación continua tiene como objetivo revertir las condiciones en el cerebro que propician una sobreestimulación eléctrica y por ende acabar con las convulsiones del paciente. Como propósito principal se tiene desarrollar un dispositivo de bajo costo que pueda replicar la eficacia del tratamiento VNS (Vagus Nerve Stimulation) y así poder brindar apoyo a las instituciones neurológicas de toda Guatemala. La gran mayoría de pacientes con epilepsia no cuentan con los medios para optar por tratamientos farmacológicos. En el caso donde los fármacos no son una alternativa, estos procedimientos y dispositivos de tratamiento son aún más limitados debido a su costo y distribuidores.

Se plantea continuar con el trabajo de las fases previas para poder lograr una unificación de los módulos de estimulador y la varilla programadora para poder iniciar pruebas en el futuro próximo. El diseño y desarrollo del presente dispositivo se encuentra basado en el módulo de estimulación de LivaNova VNS Pulse 102 y su correspondiente varilla programadora. La unificación consiste en lograr la comunicación inalámbrica entre los módulos, así como la fabricación de un circuito impreso y una carcasa para la varilla programadora . Por último, se propone realizar una réplica del equivalente del nervio vago para poder probar la funcionalidad de la electrónica en un contexto más parecido al del tejido vivo.

### Antecedentes

Tratamiento VNS de LivaNova

En el contexto de la epilepsia, la epilepsia refractaria/fármaco-resistente es una condición que, aunque rara, representaba un reto en el contexto de la medicina moderna. El mundo de la medicina actual este fabricado para diseñar soluciones convenientes a pacientes de diversas condiciones crónicas. Como parte de los retos de tener una condición crónica (que muchas veces es congénita) es que las opciones de tratamiento tienen que resultar eficientes y económicos para los pacientes que tienen que lidiar con estas condiciones por el resto de su vida. El enfoque para el tratamiento de la epilepsia se centra en proveer al paciente con una dosis adecuada de antiepilépticos. Sin embargo, en ciertos casos, los síntomas secundarios de dichos medicamentos pueden resultar inconvenientes para pacientes que cuentan con otras condiciones. Específicamente en el caso de los pacientes de epilepsia refractaria, la utilidad de los antiepilépticos resulta nula, debido a que existe una resistencia bio-química a los componentes de estos medicamentos que tratan actuar sobre el sistema límbico y el sistema nervioso. En respuesta a la falta de alternativas, LivaNova decidió lanzar un neuromodulador que busca atacar el problema de las epilepsias utilizando descargas eléctricas controladas dirigidas al nervio vago. Este tipo de neuromodulación se conoce como Estimulación de Nervio Vago o Vagus Nerve Stimulation (VNS). Esta técnica de estimulación busca provocar una serie de descargas controladas y periódicas al nervio vago para que estas descargas puedan afectar partes específicas del cerebro para combatir los síntomas que provocan las convulsiones. La exposición por largos periodos de tiempo ha demostrado una reducción significativa en la incidencia de ataques epilépticos en pacientes con epilepsia refractaria del 81 %. también se ha reportado que, en este mismo grupo de pacientes, hasta un 12 % de estos pararon de reportar convulsiones por epilepsia luego de un periodo de 10 meses bajo el tratamiento [1].

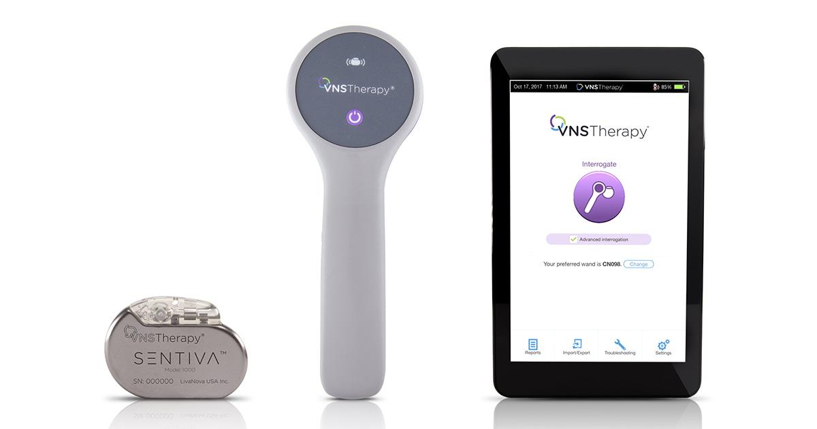
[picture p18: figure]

Figura 1: Estimulador y Varilla programadora de VNS [1].

LivaNova: VNS Pulse 102/102R-Aspire 106

De la línea de productos de LivaNova, se tiene una serie de estimuladores para el tratamiento por estimulación de nervio vago (VNS). Estos estimuladores cuentan con una aleación de titanio bio-compatible. Estos estimuladores operan según una serie de parámetros que son programados por el médico encargado utilizando una varilla programadora inalámbrica. Los parámetros determinan la frecuencia, amplitud y ciclo de trabajo del PWM que se utiliza para la estimulación del nervio vago. El trabajo previo en esta línea de investigación está basado en el modelo de LivaNova: VNS Pulse 102. Este modelo de estimulador de nervio vago cuenta con dos partes, un estimulador y una varilla programadora donde el médico puede fijar los parámetros de estimulación para el tratamiento individualizado de cada paciente. Se escogió este prototipo debido al tamaño y disponibilidad de este. El desarrollo que se llevó acabo en la fase 1 y la fase 2 de esta línea de investigación utiliza el VNS Pulse 102 como la línea basal de indicadores de éxito para la funcionalidad del mismo dispositivo. El modelo 102 cuenta con funcionalidad más limitada que los modelos posteriores, pero ofrece la versatilidad de que la construcción de este y la electrónica que hace que el mismo funcione se encuentran disponibles y cuentan con componentes que se podría considerar como básicos bajo el criterio de precio en el mundo de la electrónica para aplicaciones médicas. Sin embargo, el precio actual del tratamiento por estimulación de nervio vago es de $20,000 [2]. Esto presenta un reto para los pacientes con epilepsia refractaria que no tienen otros medios para lidiar con su condición, que resulta en un impedimento serio en la vida cotidiana, profesional y personal. Por ende, a partir de las características del dispositivo, se buscaba recrear un dispositivo que pudiera aplicar el tratamiento según las especificaciones de LivaNova y tener funcionalidad muy parecida por una fracción del costo [3]. Basándose entonces en las características del Pulse 102 y Aspire 106 se desarrolló un modelo que pudiera aplicar el tratamiento y pudiera funcionar en un ambiente con condiciones cambiantes y generalmente impredecibles como lo son con el cuerpo humano. El Pulse 102 (2) ofrece la conveniencia de ofrecer dos modalidades de funcionamiento, una automática y otra que permite la intervención manual. Este encapsulado tiene dimensiones de 6.9 mm × 55.2 mm

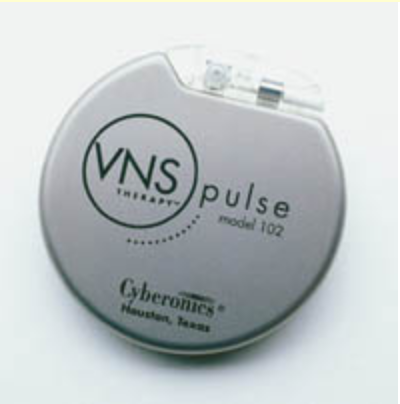
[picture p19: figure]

Figura 2: VNS Pulse 102 de LivaNova [3].

× 51.6 mm, y tiene un peso aproximado de 25 gramos [4]. El dispositivo no cuenta con un puerto para recibir una recarga por inducción o con algún medio de cargar el dispositivo sin sacarlo del cuerpo. Dadas las características de la batería, el dispositivo cuenta con una expectativa de vida de entre 3-8 años, siendo 6 años la media (todo dependiendo de los parámetros de configuración para las descargas) [4]. Este es el modelo mas antiguo y con mas tiempo en el mercado. Este fue patentado por Cybertronics en 1997, y aprobado por la FDA (Food and Drug Administration) en 1998[[5]]. Teniendo así el dispositivo 13 anos de haber sido introducido al mercado. En el caso del nuevo modelo, AspireSR 106 3 se tiene

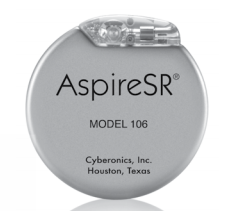
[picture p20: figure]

Figura 3: AspireSR modelo 106 de LivaNova [3].

que este modelo cuenta con 3 modos de operación que se adaptan a las necesidades del paciente[[3]]. En el modo Standard se administran descargas cíclicas como parte del tratamiento. Estas descargas son independientes del contexto en el que se encuentre el paciente y actúan a metafóricamente como una medicina que se tiene que ingerir cada cierto tiempo. En el modo Magnet, el paciente puede administrar una descarga manualmente al contactar dos piezas magnetizadas que activan en torno un sensor de efecto Hall. Este modo de operación, el paciente tiene mayor control sobre las descargas y puede actuar pro-activamente para detener o frenar un ataque de epilepsia antes de que suceda. El punto de venta de este modelo en particular es el modo de detección automática que se activa en respuesta a un incremento a el ritmo cardiaco >21 %, que típicamente indica el inicio de un ataque de epilepsia. Una vez que se cumple el parámetro del incremento súbito del ritmo cardiaco, este modo de operación envía pulsos eléctricos con mayor amplitud para prevenir el inicio del ataque. Las características de dicho modelo, que se encuentran detallado en el manual para el médico indican que las características de este modelo de dispositivo son las siguientes:

Cuenta con dimensiones de 2plg × 2plg × 0.2plg, un peso de 0.88 oz. Tiene una cubierta de titanio herméticamente sellada, bloques de conexión de acero inoxidable, un asiento de conector de silicona y unos cabezales de Poliuretano. Dichos materiales, a nivel subcutáneo, son todos bio-compatibles y seguros a la hora de insertar en un ser vivo. Para la electrónica. este modelo cuenta con una batería de 3.3 volteos, con una capacidad de 1.7 Ah de Litio al carbono. Cuenta con reguladores de voltaje, un cristal oscilador, módulos de lógica y de control (microcontrolador), una antena para recibir la señal del programador, un sensor magnético y una terminal de entradas y salidas donde genera la descarga para detener/prevenir el ataque de epilepsia.

Fase Previa

Este protocolo detalla el trabajo a realizar en la tercera fase de desarrollo del proyecto del estimulador de nervio vago. En las fases previas se trabajó en la elaboración de un sistema de neuromodulación utilizando PWMs de Amplitud variable en forma de un tren de pulsos. También se trabajó en el prototipo de una varilla programadora que permite cambiar los parámetros de estimulación de manera inalámbrica. Todo esto con el propósito de la fabricación de un prototipo que pudiera ofrecer la funcionalidad del VNS Pulse 102 de LivaNova, a un precio menor que el tratamiento que ellos ofrecen comercialmente. Se discutirán los hallazgos, desarrollo y limitaciones encontradas en la fase II del proyecto.

### 1. Estimulador de Nervio Vago-Fase Previa

La primera de las dos partes en las que se repartió el proyecto del estimulador del nervio vago consiste en el módulo de estimulación que se pretende insertar en el paciente. Dicho modulo tiene como objetivos, ser de bajo costo y cumplir con los parámetros de descarga y modos de operación para poder tratar la epilepsia fármaco-resistente. Dicho modulo está inspirado directamente por el VNS Pulse 102 y AspireSR 106 de LivaNova. El prototipo actual del estimulador cuenta con funcionalidad básica, y está en un proceso de transición a un encapsulado comercial y a la ampliación de funciones de este.

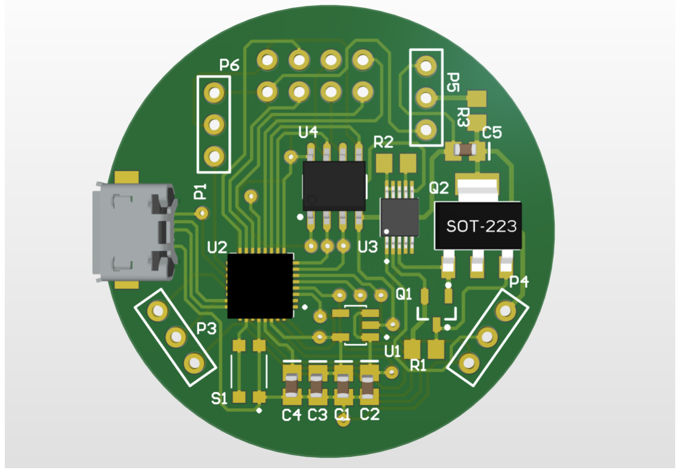
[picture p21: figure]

Figura 4: Prototipo Final del Estimulador de la Fase 2 [6].

Desarrollo y Resultados

En la fase II del Estimulador de Nervio Vago trabajada por Gustavo Ordeñes[6], se logró mejorar la funcionalidad del prototipo del estimulador de nervio vago desarrollado inicialmente en la fase I. Las mejoras desarrolladas en la segunda fase incluyen una descarga más controlada con la implementación de un modo rampa, la selección de microcontrolador más eficiente (SAM21E18A/Trinket M0 ) en su consumo de potencia para el prototipo del estimulador, además de varias mejores a la propuesta del circuito previo y el PCB. Se logró una reducción de área del PCB de un 20 %, con características físicas que se asemejan más al VNS Pulse 102 . Esto se logró con la creación e implementación de un PCB de dos capas para una distribución más eficiente de los componentes. También se movió de componentes THT a SMD, reduciendo el grosor del prototipo. Se logró determinar que la capacidad mínima para la batería del estimulador tiene que ser de 700mAh para cumplir con los requerimientos de funcionalidad del dispositivo. También se logró reducir aún más el consumo energético del estimulador utilizando un modo´´sleep” que pone al dispositivo en modo de bajo consumo entre descargas. Por último, pero no menos importante, se logró la creación de un dispositivo estimulador cuyo precio por componentes (sin considerar costos de fabricación) se encuentra alrededor de $ 25.6 (o Q200).

Alcance y Limitaciones

En esta fase se logró que el dispositivo cumpliera con dos de los tres modos de operación encontrados en el AspireSR 106 [3]. Como parte de las limitaciones del prototipo actual del estimulador, es que no se tiene una fase de operación de ´´auto detección” que se active con un parámetro de agotamiento, tal como el incremento del ritmo cardíaco en el AspireSR 106. Este modo de operación es conveniente y muchas veces vital para el tratamiento preventivo y la seguridad de los pacientes con epilepsia refractaria. Otras de las áreas de oportunidad existen en que el consumo de potencia del prototipo de estimulador actual puede ser reducido al transicionar de un regulador de voltaje (que tiene un consumo significativo de potencia para un encapsulado tan pequeño) a un regulador dual tipo Buck/Boost. También se puede reducir el consumo de potencia aún más, desactivando ciertas funciones del SAMD21E18A que permanecen activas en el modo de operación normal, pero que no son utilizadas en la programación del estimulador. Aunque quedo diseñado en software, no se tiene en programación los medios para poder comunicarse de manera inalámbrica con la varilla programadora y tampoco existe la placa física que cuente con el modulo SPSGRFC-868 para la comunicación inalámbrica. Por último, hace falta el desarrollo de un encapsulado y sistema de potencia bio-compatible para el estimulador.

Varilla Programadora para Estimulador de Nervio Vago-Fase Previa

Desarrollo y Resultados

En la fase II de la Varilla programadora para el Estimulador de Nervio Vago trabajada por Miguel Álvarez se logró una mejora significativa en él envío y recepción de datos por parte de la varilla programadora, la interfaz de programación y el estimulador [7]. Se desarrollaron dos protocolos de comunicación por medio de USART y Wifi. Se creó una interfaz gráfica en Python que luego se exportó como un´´.exe” (archivo ejecutable) para su fácil distribución y uso en computadoras. Se redujo el tiempo de envío de mensajes por comunicación inalámbrica a 11.35 ms [7]. También se realizó un cambio de componentes, donde se utilizaron módulos RF más pequeños. Se demostró que se puede programar el dispositivo a través de una pared de tejido carnoso, simulando las condiciones del estimulador en tejido subcutáneo. Todas las mejoras al código previo y la implementación de una interfaz de programación le dan al prototipo una utilidad agregada que se encuentra en el modelo comercial. Además acercan a el proyecto a eventuales pruebas en humanos, donde se podría verificar la utilidad de lo planteado en el mismo.

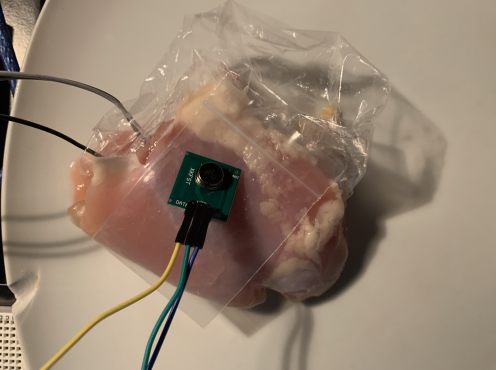
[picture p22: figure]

Figura 5: Prueba de transmisión a través de tejido carnoso de la Fase 2 [7].

Alcance y Limitaciones

Lo que se indica para la varilla programadora, es que las mayores limitaciones de la varilla programadora existen en su falta de estructura física y falta de soporte independiente a la hora de funcionar. Con esto se indica que la varilla programadora no cuenta con una fuente de energía independiente para poder usarla desconectada de una fuente de poder. Con esto va de la mano que falta un estudio de consumo de potencia y eficiencia de la actual propuesta para la varilla programadora. también, la varilla no cuenta con un cuerpo/estuche como tal. El diseño de esta se encuentra limitada a los componentes interconectados mediante cables en un protoboard. todavía no existe un PCB como tal para la varilla programadora como tal. también existe la necesidad de migrar de un módulo inalámbrico independiente, a un microcontrolador que cuente con funcionalidad inalámbrica integrada (tal como el ESP8266). Esto, debido a que reduce la huella del circuito y reduce la complejidad del Código, al simplificar la conexión a una red directamente del mismo microcontrolador. también esto significa una reducción de costos para los prototipos siguientes. Se advierte que, de usarse un módulo independiente de conexión inalámbrica, se considere en usarse un módulo que pueda soportar hasta 5V en sus terminales, para así también eliminar la necesidad de utilizar un regulador de voltaje. Se advierte que la frecuencia en la que se realiza la conexión entre la varilla y el estimulador, idealmente debe existir en una banda de frecuencia diferente a las frecuencias cotidianas, para evitar contaminación de la señal. Por ahora, las pruebas en tejido que se hicieron por parte del programador requieren de otras pruebas en un medio biológico que se acerque más al tejido humano/animal. De esta manera se pueden simular de manera más realista las condiciones de operación del dispositivo.

### Justificación

Se calcula que alrededor del mundo, existen unos 50 millones de personas que padecen de epilepsia. Condición que impide de maneras diversas el funcionamiento y la integración de estas personas a la vida laboral y a la vida cotidiana. De estas, 10 % viven en latino-América. Junto con eso, se calcula que alrededor del 80 % de las personas con esta condición, provienen de hogares con bajos ingresos. Esto limita directamente las posibilidades de que, si en primer lugar se lograra diagnosticar de manera correcta la epilepsia, estas personas pudieran hacer una recuperación; o por lo menos pudieran optar a vivir con su condición controlada. Se estima que alrededor del 75 % de las personas que son diagnosticadas con epilepsia, no son tratadas de manera adecuada [2].

Estos hechos demarcan una realidad, en donde existe una condición real y problemática que podría ser tratada y podría cambiar las vidas de millones de personas. Sin embargo, existen diversas barreras que limitan la ayuda que estas personas pueden recibir. La idea de tener una condición que no solo puede atacar en cualquier momento, sino que puede robar a las personas de instantes preciados de sus vidas es alarmante. No solo es una condición compleja y muchas veces incomprendida por el público en general, sino que es algo que afecta la esencia de ’el ser’, nuestro cerebro. Muchas de las víctimas de epilepsia no son pacientes que de manera ’caricaturesca’ tienen convulsiones que provocan movimientos exagerados y violentos. Las convulsiones se pueden esconder detrás de una mirada perdida, o detrás de un paro repentino. En esos instantes donde las personas quedan sin control de sí mismas y aquellos alrededor de la víctima tampoco pueden identificar que está pasando, solo queda un aire de confusión seguido de un juicio silencioso. Se podría suponer que, dados los avances en la medicina antiepiléptica, la única limitante es el acceso a dichos fármacos. No obstante, hay casos donde los antiepilépticos no son una opción. ¿Qué sucede con las personas que no pueden optar a tratamientos convencionales, no por falta de recursos, sino por la falta de efectividad de estos? Este es el caso de las personas que lidian con epilepsia refractaria, también conocida como epilepsia farmacorresistente. Alrededor de 25 % de las personas con epilepsia, padecen de epilepsia fármaco resistente (EFR) EFR. Muchas de las personas que inician con algún tipo de epilepsia tratable, evolucionan a tener EFR. ¿Qué se puede hacer en esos casos?

Este fue el planteamiento que llevo a la concepción y el desarrollo del tratamiento de estimulación de nervio vago, o VNS por sus siglas en ingles. Buscando ser una alternativa a el tratamiento fármaco-químico que busca limitar y controlar la actividad eléctrica cerebral, VNS busca reestructurar los patrones de descarga y funcionamiento del cerebro para tratar la causa de la epilepsia y detener los ataques de forma pro-activa [3]. Por medio de un dispositivo implantado entre el cuello y el pecho, descargas eléctricas controladas son emitidas al cerebro en intervalos constantes y controlados, buscando ajustarse al tipo de epilepsia que presenta el paciente. El pionero en el campo de terapia VNS es LivaNova. Ellos ofrecen el equipo estimulador, programador y la cirugía de inserción por un precio de alrededor de $20,000. Esto nos devuelve a una de las grandes problemáticas que encapsulan la epilepsia. La mayor parte de los pacientes que padecen de epilepsia, no cuentan con los ingresos para optar por antiepilépticos ($30-$1000). Mucho menos van a poder costear la operación y las visitas consecuentes al médico, para monitorear y ajustar el estimulador de manera adecuada. Fuera del problema de los recursos monetarios, dado que es una tecnología emergente en los últimos 10 años, no hay suficientes médicos que conozcan de este tipo de alternativas, mucho menos médicos certificados en Guatemala que puedan realizar el procedimiento y monitorear un paciente. En general en el contexto de un paciente con EFR en Guatemala, las opciones parecen no existentes [8].

Con esto en mente, se comenzó con el desarrollo de una alternativa costo eficiente para el módulo estimulador y programador de tratamiento VNS en la Universidad del Valle. Tomando como referencia el VNS Pulse 102 de Liva Nova, se inició un proyecto separado en distintas fases, cuyo objetivo era desarrollar un dispositivo con funcionalidad comparable a dicha referencia. Tomando en cuenta que en Guatemala hay 325,000 personas que padecen de epilepsia, eso quiere decir que alrededor de 81,250 personas padecen de epilepsia refractaria [9]. Si se pudiera ofrecer un dispositivo accesible a este número de personas, no solo se están cambiando miles de vidas, sino que abriría las puertas también a otros tipos de descubrimientos y desarrollos en el campo de la neurología. Nadie merece vivir impedido por una circunstancia que escapa de su control, solo porque la persona no tiene los recursos necesarios para acceder a algo que está claramente disponible.

De la fase pasada, se lograron hacer mejoras clave al funcionamiento del prototipo inicial de estimulador de nervio vago [6]. Tambien se trabajo en el desarrolló de una varilla de programación que permitiera mandar los parámetros de forma inalámbrica junto con una interfaz de usuario [7]. Por el momento cada parte del tratamiento, la varilla y el estimulador, se encuentran separados uno del otro. Con esto se entiende que todavía la varilla no puede programar al estimulador directamente (fuera de una simulación). Para poder acercarse cada vez mas a cumplir el objetivo inicial de desarrollo, se necesita un prototipo que pueda ser programado de manera inalámbrica a través de tejido vivo. Con un prototipo que pueda incluir la funcionalidad de las fases pasadas, y que se pueda programar de manera inalámbrica, se podría comenzar el largo proceso de pruebas clínicas. Por lo tanto, lo que se plantea es poder modificar el prototipo de estimulador existente para agregarle funcionalidad inalámbrica y una carcasa. Tambien se quiere mejorar el prototipo de varilla programadora, al diseñarle un circuito impreso y diseñar una carcasa que permita tener todos los componentes en algo que pueda ser sujetado con una sola mano.

Estos cambios no solo son necesarios para las futuras iteraciones del proyecto, sino que son cruciales para que se puedan interactuar con ambos módulos de del tratamiento VNS de manera fácil e intuitiva. Como se encuentra ahorra el proyecto, solo alguien con conocimiento directo de la programación y del ensamblaje de los componentes seria capaz de emular el diseño y modificar los parámetros de estimulación. Lo que se quiere entonces es proponer un diseño base para que en futuras iteraciones solo se necesite trabajar en refinar y mejorar dicho modelo. El valor intrínseco de los aportes propuestos a este proyecto esta en la unificación de dos partes que fueron trabajadas por separado y que ahora deben de volver a ser la combinación que conforma al prototipo del producto final. Todo esto con el valor agregado de iniciar el proceso de investigación y desarrollo de una carcasa con materiales bio-compatibles para eventualmente poder hacer pruebas en seres vivos.

### Objetivos

Objetivo General

Optimizar e Integrar los módulos de estimulación de nervio vago y la varilla programadora desarrollados en la fase anterior del proyecto y prepararlos para pruebas en tejido animal.

Objetivos Específicos

Integrar el modulo de la varilla programadora con el estimulador para para lograr programación de manera inalámbrica.

Desarrollar circuitos impresos para el estimulador de nervio vago y el circuito de la varilla programadora.

Desarrollar una interfaz física portátil para la varilla programadora.

Evaluar opciones de encapsulado bio-compatible para el estimulador de nervio vago.

Reducir el consumo energético del sistema de programación inalámbrico y afinar el funcionamiento del sistema combinado de estimulador y programador.

### Marco teórico

Epilepsia

La epilepsia es el diagnóstico de un trastorno cerebral crónico donde se tienen convulsiones de manera regular y fuera de un contexto específico. La epilepsia se puede manifestar de varias maneras, pero algo en común que tienen los diferentes tipos es que involucran una reacción involuntaria provocada por un auge de actividad cerebral [10]. La sobre excitación neuronal puede ser una condición congénita o causada por una serie de factores diversos provocados por una herida o una enfermedad subsecuente. La sobreexcitación puede involucrar de manera parcial o total todo el cerebro, y dependiendo de cómo esta se presente, tiene como consecuencia diferentes tipos de convulsiones. La epilepsia es un riesgo a la vida del paciente no porque la condición mate a la persona directamente, sino que la incapacidad de controlar las extremidades o mantener conciencia puede poner a las personas en situaciones de alto riesgo que pueden causar heridas graves que pueden costar la vida a los pacientes. Debido a que no se puede predecir el contexto en el que se presentan las convulsiones, y el tipo de estas, el tratamiento de dicha condición trata de atacar la base del problema farmacológicamente. El contexto de la actividad neuronal involucra una serie de polarizaciones y despolarizaciones del tejido neuronal provocado por la liberación de iones de Sodio(N a⁺), Calcio(Ca⁺) y Cloro(Cl⁻) que controlan la secreción de glutamato que se convierte en un ’puente’ que dirige la descarga de eléctrica provocada entre las terminales polarizadas de dos sinapsis [11]. Este sistema de descargas va de la mano con un sistema de respaldo en la forma de neuronas inhibidoras. Este sistema de inhibición tiene como propósito absorber parcialmente los iones que van de una neurona a otra, para así reducir el nivel de actividad y también para despolarizar las neuronas de activación cercanas luego de que termine la conducción. Las convulsiones ocurren cuando un conjunto de factores previene ambos sistemas de manera adecuada. Por alguna razón/trauma las neuronas de activación se encuentran sobreexcitadas, por lo que secretan más glutamato del que es necesario. También coincide que el sistema de inhibición neuronal tiene problemas para despolarizar las sinapsis adyacentes, lo que resulta en un periodo donde el grupo de neuronas tiene un periodo de transmisión no deseado. Esto resulta a una reacción en cadena (que puede o no ser localizada) que altera la actividad cerebral normal e induce lo que se podría pensar como una sobre corriente en el cerebro. El diagnóstico de la epilepsia se puede hacer con los siguientes métodos [8]:

Síntomas: Si se pueden detectar periodos de pérdida de conciencia en el paciente, o si se pueden identificar series de movimientos involuntarios que suceden de manera crónica o esporádica se puede diagnosticar epilepsia. Se necesitan hacer más preguntas para identificar el tipo de convulsiones y el tipo de crisis referente a el diagnostico de epilepsia del paciente

EEG: Se pueden identificar patrones de actividad cerebral anormalmente altos. también se puede identificar la duración de las crisis. además, puede servir como una herramienta que le ayuda al paciente a identificar síntomas previos a un ataque.

Historial Médico: Muchas personas con epilepsia congénita, que no padecen de convulsiones tónicas, no saben que tienen epilepsia hasta ya mayores. Debido a que las convulsiones se pueden presentar como periodos de ausencia breves, mucha gente cree que estas personas solo (como se diría coloquialmente) ’pierden el hilo’. Estudiando los sitios más recurrentes que las personas con convulsiones atónicas presentan, puede ayudar a identificar el diagnostico de epilepsia.

Pruebas genéticas: En los casos infantiles y donde existen si tomas congénitas, se pueden realizar pruebas en diferentes grupos genéticos para identificar problemas como un sistema nervioso inhibidor ausente, o problemas en los receptores de iones. también hay grupos de bases que sirven para identificar problemas con los caminos de glutamato. Si se pueden ver defectos genéticos en las muestras de la persona, estos pueden dar indicios de la condición, pero estas pruebas se hacen en conjunto con las previamente mencionadas para fortalecer el diagnostico.

Tipos de Convulsiones

Una convulsión es una ´´alteración eléctrica repentina y no controlada en el cerebro” (NIH,2021). Las convulsiones pueden suceder como respuesta inmediata a un trauma y no son diagnosticadas inmediatamente como epilepsia. Cuando existen sobrexcitaciones en la actividad neuronal del cerebro, que ocurren de manera periódica o en respuesta a situaciones con condiciones específicas es que se puede denotar a un paciente que padece de epilepsia. La manera en que la sobreexcitación neuronal impacta el cerebro depende de si esta excitación es de tipo localizada o si ocurre a lo largo de ambos hemisferios del cerebro. A partir de la localidad emergente de se pueden subdividir las convulsiones en dos ramas y sus consecuentes subramas. Las subramas que definen las convulsiones en ambos grupos se ven determinadas por el tipo de impacto que producen al cuerpo [8]. Ambos tipos grupos de convulsiones tienen un riesgo intrínseco para el paciente, pero dada la naturaleza de las convulsiones que afectan todo el cerebro, estas tienden a presentar un mayor riesgo. Los dos grandes grupos en los que se subdividen las convulsiones son (Ver la Figura 6):

Parciales/Focales: Convulsiones que se encuentran en un área específica del cerebro y afectan una localidad especifica de la corteza cerebral. Este son el tipo de convulsiones que la gran mayoría del público general desconoce, ya que estas no presentan síntomas igual de obvios que el caso de las convulsiones generalizadas [12].

- Focal Simple: El paciente no tiene una pérdida de conciencia, pero demuestra acciones que serían consideradas anormales. Desde cambios repentinos en las emociones, sensaciones sensoriales anormales (un olor o sabor desconocido, un sonido repentino), espasmos musculares repentinos hasta un ataque de ansiedad. El problema de este tipo de convulsiones es que el muchas veces el paciente y los profesionales tienden a diagnosticar la condición por otras enfermedades dado que esta se presenta muchas veces en la forma de trastornos emocionales. Las personas que esta condición pueden pasar toda su vida sin saber que son epilépticos hasta que se les realiza un EEG. Por ende, es de suma importancia tomar nota de todos los síntomas que presenta el paciente, aunque estos no se manifiesten de manera física. Todo indicio de cambios repentinos puede resultar un buen indicador para que le pueda realizar una prueba al paciente. Existen tipos de convulsiones focales que se conocen como ´auras’ [12].
- Aura Motora: Movimiento repentino de una de las extremidades del cuerpo. Se puede denotar en que hemisferio del cerebro está sucediendo la convulsión focalizada al notar de qué lado suceden los espasmos musculares.
- Aura Sensorial: Se tienen problemas con los sentidos, y pueden presentar alucinaciones/hacer al paciente experimentar cosas que no se encuentran en su entorno inmediato
- Aura Autonómica: Alteran las funciones involuntarias del cuerpo (Sistema nervioso autónomo). Pueden causar incrementos de presión, alteraciones en el ritmo cardiaco, problemas del colon o de vejiga, etc.

- Aura Psíquica: invocan pensamientos o memorias. Alteran las emociones del paciente de manera repentina. Pueden dar una sensación de deja vú.
- Focal Compleja: Cuando la sobreexcitación cerebral resulta en la perdida breve de conciencia del paciente. El paciente demuestra una mirada perdida, un lapso de memoria en el periodo que sucede la convulsión. Debido a que está perdida de conciencia no se manifiesta como la perdida de actividad motora, las personas pueden experimentar convulsiones y no darse cuenta de estas. Fuera de la mirada ausente, de solo ver al paciente es difícil distinguir que no están conscientes. Muchas veces son precedidas por un ´Aura’, que luego se desata como una pérdida de conciencia absoluta [12].

Generalizadas: En este tipo de convulsiones, se ven afectados ambos hemisferios del cerebro de manera simultánea, por lo que se induce una pérdida de conciencia y en ciertos casos, perdida de las funciones motoras de manera esporádica. Estas son las convulsiones de mayor riesgo para el paciente, ya que alteran impiden el funcionamiento del cuerpo/ impiden las funciones motoras normales del paciente durante un ataque [9].

- Generalizada Tónica: En un determinado grupo de músculos, el tejido muscular se tensa y adquiere una rigidez anormal. Durante este periodo de rigidez, no se puede relajar las fibras musculares, lo que impide actividades normales como caminar o inclusive mantenerse de pie. Estos periodos de rigidez pueden durar varios segundos y causan gran estrés al cuerpo del paciente.
- Generalizada Clónica: Se generan sacudidas o temblores en las extremidades del cuerpo. Estos temblores no tienen que suceder en todas las extremidades, sino que pueden suceder
- Generalizada Tónica-Clónica: Este es el tipo de convulsión que la gente se imagina cuando se da el diagnostico de epilepsia. Se tienen periodos en los que se dan sacudidas violentas, seguidas de periodos de rigidez en intervalos cortos. La persona muestra movimientos descontrolados, y debido a los patrones musculares anormales, la gran mayoría de veces los pacientes caen al piso y no son capaces de mantenerse de pie.

Epilepsia Refractaria

La palabra ´refractaria’ es un sinónimo de la palabra ´obstinado’ y de la palabra ´persistente’. En términos médicos, las enfermedades refractarias son aquellas que no reaccionan ante el uso de los tratamientos/medicamentos comunes [6].
"La epilepsia es refractaria cuando las crisis epilépticas son tan frecuentes que limitan la habilidad del paciente para vivir plenamente acorde con sus deseos y su capacidad mental y física o cuando el tratamiento anticonvulsivo no controla las crisis o sus efectos secundarios son limitantes para un desarrollo normal de la persona"(Garcia 2017). El caso de la epilepsia refractaria o farmacorresistente es el diagnostico que se le da a un paciente con epilepsia para el cual los AEDs no representan una mejora en su condición. Para estos pacientes las opciones de tratamiento son nulas/limitadas. Esto resulta serio, dado que las crisis epilépticas evitan el desempeño funcional del individuo en cualquiera que sea su área de operación

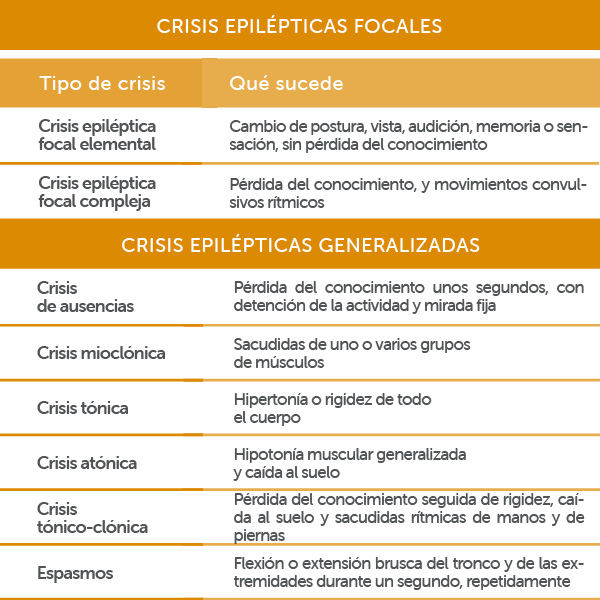
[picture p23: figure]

Figura 6: Tipos de Convulsiones [8].

[13]. El riesgo de un ataque que puede poner a los individuos en condiciones peligrosas limita la manera en que estos individuos viven sus vidas. Existen diversas explicaciones de porque los múltiples y diferentes AEDs no funcionan en estos individuos, y dichas explicaciones se pueden definir en los diferentes tipos de refractariedad (o tipos de resistencia) que desarrollan o presentan de manera congénita estos individuos [14].

Tratamiento de estimulación de Nervio Vago (VNS)

Este tratamiento busca aprovechar la conexión que tiene el nervio vago a la medula espinal para poder cambiar el comportamiento electroquímico del cerebro. Se ha estudiado que el entregar descargas controladas por periodos prolongados de tiempo a la corteza cerebral, puede revertir y reconfigurar la manera en que se maneja el potencial eléctrico entre las sinapsis de las neuronas. Al estar en un estado de sobreexcitación permanente, la respuesta natural del tejido neuronal es la de incrementar el parámetro de disparo entre las neuronas. Puesto en otras palabras, se necesita un potencial de acción mayor para poder activar la serie de pulsos que se convierten en un mensaje en la fibra nerviosa. Esto quiere decir que bajo las condiciones de excitación que generan una convulsión, se logra detener la reacción en cadena dado que la amplitud de la sobre excitación no es lo suficientemente grande como para generar una polarización y posteriormente una descarga eléctrica [3]. El proceso y el funcionamiento de como los pulsos que se le entregan a la medula espinal por medio del estimulador y como estos alteran la electroquímica del cerebro no es entendida por completo. Sin embargo, puede pensarse similar al funcionamiento de un marcapasos. En donde este dispositivo busca funcionar de manera correctiva, y dictar lo que constituye la actividad eléctrica normal del cerebro. En el momento que la actividad cerebral del cerebro busca salirse de control, esta tiende a buscar su referencia basada en las descargas entregadas por el estimulador. De esta manera no solo se pueden tratar las convulsiones a largo plazo, sino que se pueden dar descargas de manera reactiva para evitar una serie de convulsiones antes de que estas se salgan de control y el paciente pierda la conciencia. Este tratamiento depende de dos equipos. El primero, es el estimulador que entrega las descargas al paciente. La segunda es el equipo o varilla de programación que permite modificar los parámetros de dichas descargas de manera inalámbricas, sin necesidad de remover el dispositivo una vez que este se encuentre implantado en el paciente [1].

Estimulador de Nervio Vago

El corazón del funcionamiento de la terapia VNS. Este dispositivo que es implantado entre la región del pecho y el cuello por donde pasa una de las regiones más densas del nervio vago, es el encargado de entregar descargas de manera periódica y reactiva a el nervio vago. Dichas descargas no son simples cadenas de pulsos cuadrados, sino que estas siguen un incremento y reducción de amplitud que le permiten al cuerpo reaccionar de manera adecuada. El estimulador utiliza algo que se conoce como ´rampas’ para entregar una descarga que incrementa en amplitud en un periodo de tiempo lo suficientemente grande como para que la misma descarga no genere algún movimiento o reacción indeseada. así como hay una rampa de subida, también hay una rampa de baja, que permite la relajación/despolarización natural del tejido nervioso en el nervio vago. Dichos trenes de descargas y sus frecuencias deben ser moduladas y ajustadas por el médico que está encargado del paciente [6]. En donde el médico puede reducir o incrementar la amplitud y cantidad de pulsos dependiendo la gravedad de las crisis convulsivas que experimenta el paciente. además del sistema de potencia que genera y modula dichas descargas, existen otros dos elementos que son fundamentales para el funcionamiento del estimulador. El primero es el módulo de comunicación inalámbrica. Este módulo permite recibir la información que manda la varilla programadora a través del tejido. también permite monitorear la condición y el funcionamiento del dispositivo una vez que este se encuentra dentro del paciente. El segundo elemento es el encapsulado de titanio que hace que el estimulador sea bio-compatible. Este elemento y los materiales que lo conforman aseguran que no haya una respuesta agresiva/indeseada del cuerpo al encontrarse este con un agente externo y composición tan diferente a la del tejido interno. Es vital para poder colocar el dispositivo en el paciente y que, a la hora de sanar, el tejido crezca de la manera adecuada alrededor del dispositivo y que este quede en el lugar donde debe de estar [4]. también existe un tercer elemento en ciertos modelos, siendo este un sensor de ’efecto hall’. Este fenómeno permite cerrar un circuito cuando este se encuentra en la presencia de un campo magnético lo suficientemente fuerte. Con este componente adicional se pueden tener mayor funcionalidad del dispositivo, como optar porque el paciente tenga la opción de descargas manuales o de emergencia [1].

Varilla Programadora

El tratamiento VNS no sigue un mismo estándar para cada paciente. El contexto de las convulsiones y la causa general de la epilepsia cambia drásticamente de paciente a paciente. Por ende, existe la necesidad de poder ajustar el tratamiento a voluntad. Con ajustes a la amplitud, frecuencia de aplicación, y variando el ciclo de trabajo de los pulsos se puede ofrecer un tratamiento a largo plazo que minimice o completamente elimine las convulsiones [7]. Esta varilla programadora consta de dos partes, el dispositivo físico que envía los datos al estimulador de forma inalámbrica, y el dispositivo con la interfaz donde se hacen estos cambios de parámetros y se le cargan a la varilla programadora, como se puede ver en la Figura 8. La interfaz de programación debe de ser sencilla e intuida para que el doctor pueda programar los parámetros basados en un rango de amplitudes y frecuencias. La varilla programadora debe de poder emitir estos datos a un receptor que está dentro del encapsulado del estimulador, efectivamente teniendo la necesidad de poder emitir una señal que viaje a través de la piel y los músculos además de del encapsulado metálico, hasta el estimulador. La combinación de las consideraciones de usabilidad y funcionalidad de los componentes hace que la selección de componentes y materiales sea de vital importancia. Como parámetros iniciales, la recomendación es utilizar pulsos con un periodo de 250 - 500µs con un tiempo de activación de 30s seguido por un tiempo de reposo de 600s [15]. Todo esto a una frecuencia de 20 Hz. Los parámetros de programación para los pulsos pueden ser vistos en 7, donde se puede ver que la forma de la señal sigue un patrón trapezoidal con rampas incrementales y decreméntales para cuando inicia y termina un pulso respectivamente. Todo esto seguido de un periodo de reposo en donde la amplitud de la señal es de 0.

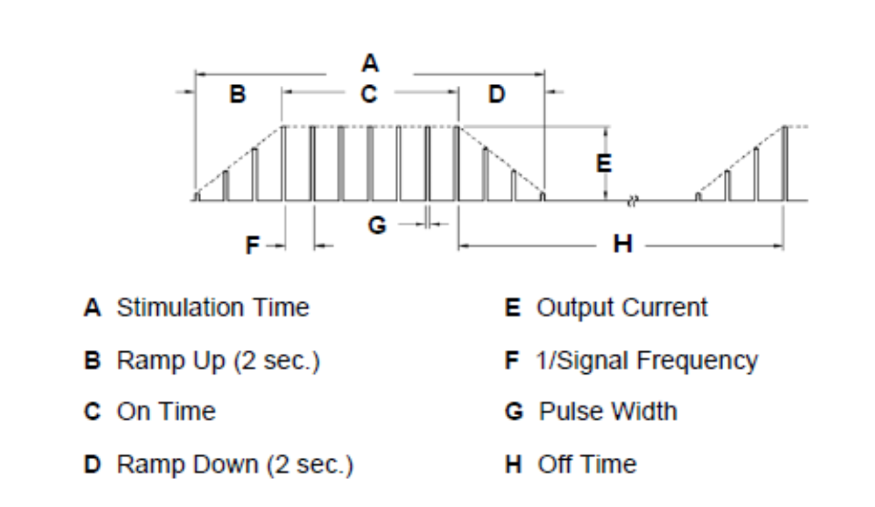
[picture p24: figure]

Figura 7: Parámetros de programación para descargas del Estimulador [3]


Figura 8: Varilla programadora y dispositivo con interfaz de programación de Cybertronics [1]

VNS Pulse modelo 102 de LivaNova

El modelo de estimulador de nervio vago del cual está basado el prototipo actual es el VNS Pulse 102 de Cybertronix. Este es un estimulador relativamente antiguo (circa 1997) de dimensiones pequeñas(ver Figura 9) que cumple con el objetivo de administrar la terapia VNS al paciente mediante la conexión del estimulador al nervio vago utilizando tres electrodos de platino (para obtener la máxima conductividad) [5]. Este dispositivo está formado por un módulo de lógica y detección que mide de manera continua los voltajes del nervio vago, un circuito generador de pulsos que pude administrar el tratamiento en periodos determinados por el neurólogo, un sensor hall que busca le presencia de un campo magnético con una magnitud específica para activar de manera automática el módulo generador de pulsos y finalmente por un módulo de lógica y programación que puede recibir parámetros de configuración exteriores por parte de una varilla programadora. Donde estos parámetros determinan las características de la estimulación por medio de una estructura de programación conocida como un look up table.


Figura 9: Medidas y características del estimulador VNS Pulse 102 [4].

Modos de Operación

Operación Normal

En el modo estándar/normal de operación el dispositivo emite descargas cada cierto tiempo para estimular el nervio vago de manera constante. Este modo de operación no tiene como objetivo detener una convulsión en proceso, sino que a través de descargas frecuentes poder ajustar la sensibilidad de activación eléctrica del cerebro y tratar la epilepsia. La administración de estos pulsos es consecuente con la tabla de valores en la figura 10 que especifica de manera directa los parámetros mínimos y máximos de estimulación que pude desplegar el dispositivo. Utilizando un circuito generador de pulsos, visto en la figura 11, que puede variar las amplitudes y los tiempos de encendido y apagado de los pulsos utilizando un controlador de lógica se puede administrar la terapia que resulte beneficiosa para el paciente y el tipo de convulsiones que este padece [1] [3].


Figura 10: Parámetros de pulsos de salida de VNS Pulse 102[1].


Figura 11: Circuito Generador de Pulsos [6].

Modo imán

Este modo de operación representa la intervención manual del usuario para prevenir una convulsión. En este modo de operación el usuario puede acercar un imán (que típicamente lleva consigo en una pulsera) a un receptáculo metálico donde se Encuentra un sensor de efecto hall que activa de manera forzosa el generador de pulsos. Al activarse el generador de pulsos dada la activación del sensor de efecto hall, se detiene cualquier descarga o proceso presente en el dispositivo y se empieza y emitir una descarga (ver figura 12) con una amplitud y frecuencia diferentes a la programada para el modo normal. Esta descarga tiene como objetivo estimular de manera forzosa el nervio vago para detener una convulsión cuando el usuario siente los síntomas previos a la misma. En este modo de operación, el dispositivo sirve como un estimulador correctivo [3].


Figura 12: Parámetros del Modo ’Iman’ del VNS Pulse 102 [1].

Modo de Detección y Respuesta

El dispositivo monitorea la actividad cardiaca del paciente. Típicamente un incremento de más del 21 % en la actividad cardiaca indica la posible presencia de hiperactividad eléctrica cerebral que puede conducir a una convulsión [12]. Muchas veces los usuarios no pueden detectar los síntomas previos a una convulsión, en especial cuando estas son parciales. Por ende, el dispositivo puede impartir estimulación preventiva al paciente sin interrumpir su funcionamiento. La ventana donde se mide el incremento de actividad cardiaca es lo suficientemente pequeño como para que el usuario pueda hacer ejercicio sin ser molestado por el sistema de auto detección activándose [5].

### Metodología

Objetivo 1: Unificar la varilla programadora con el estimulador de nervio vago

Para lograr esto se requiere primero de entender las capacidades y la funcionalidad actual de cada uno de los segmentos del estimulador por separado. El estimulador basado en un SAMD21E18A puede generar una serie de pulsos siguiendo un patrón trapezoidal. Esta cuenta programación que permite variar los parámetros de frecuencia y amplitud de la dosis que se le quiere dar al paciente. también se cuenta con la adición de un módulo de comunicación inalámbrica SPSGRFC-868, que se comunica con el emisor por medio de un protocolo SPI. El estimulador cuenta con dos modos de trabajo, el modo estándar y el modo imán. En el modo estándar, se entregan descargas programadas de amplitud constante, durante un intervalo de tiempo predefinido. Se cuenta con un circuito impreso que tiene incluido el microcontrolador, una batería, el sistema de potencia, el sensor de efecto Hall y el receptor inalámbrico.

En lo que respecta a la varilla programadora, se tiene el circuito funcional y la interfaz de programación en lenguaje Python. La varilla programadora puede comunicarse a través de un protocolo SPI entre emisor y receptor. Se demostró con tejido carnoso, que se pueden mandar los parámetros de configuración deseados a través de tejido carnoso sin problema. Por el momento, no se cuenta con un circuito impreso para la varilla programadora, ni tampoco con una estructura física que le permita operar sin el poder dado por una fuente.

Por ende, la varilla de programación es en estos momentos inmóvil.

De las pruebas realizadas en la fase previa, se logró a través de una simulación que la varilla programadora enviara los parámetros de estimulación y un receptor que luego sería incluido en la fabricación del estimulador. No se lograron hacer pruebas físicas de este suceso, y la programación que se tiene del estimulador no cuenta con ningún protocolo SPI para poder recibir los mensajes de la varilla programadora.

Esto introduce la necesidad de trasladar las pruebas realizadas en simulación, a un entorno físico donde ambos componentes tengan los protocolos de comunicación correctos para poder programar el estimulador a través de una capa de tejido. Por lo tanto, lo que se propone para poder lograr la integración de ambos componentes es lo siguiente:

Familiarizarse con la programación del estimulador y ser capaz de generar y verificar todas las modalidades de este.

Ensamblar el circuito de la varilla programadora y verificar que si este funcionando de manera correcta el protocolo de comunicación.

Añadir a la programación del estimulador el protocolo SPI que permite recibir los datos que manda la varilla programadora y poder utilizar estos datos para fijar los parámetros de estimulación basados en los estándares puestos por el Pulse 102 [3].

Hacer pruebas con la comunicación de la varilla programadora a través del módulo nRF24L01 al módulo receptor SPSGRFC-868.

Verificar que se pueda programar desde la interfaz gráfica en la computadora al estimulador de forma inalámbrica.

Objetivo 2: Desarrollo de circuitos impresos para la varilla programadora y el estimulador de nervio vago

Una vez que se tenga toda la funcionalidad preliminar, lo que se desea es poder formalizar los componentes a manera de facilitar las pruebas y la verificación de requisitos. Para hacer esto se van a realizar modificaciones al circuito impreso del estimulador y se va a diseñar y fabricar el circuito impreso de la varilla programadora. Se le quiere añadir de manera tentativa, una pantalla LCD a la varilla programadora donde se puedan ver los parámetros que esta está mandando al estimulador

Para hacer esto se van a seguir la siguiente serie de pasos:

Fabricar la placa física del estimulador con el receptor inalámbrico SPSGRFC-868

Diseñar una placa de circuitos impresos para la varilla programadora y adecuar el esquemático de dicha placa para usar los componentes más pequeños posibles (Arduino Nano en vez de un Arduino UNO, etc.).

Integrar una pantalla LCD a el circuito de la varilla programadora para poder visualizar aspectos importantes fuera de la interfaz gráfica en la computadora.

Objetivo 3: Desarrollo de una interfaz física de la varilla programadora y primero modelo de un encapsulado para el estimulador

Ya con los componentes electrónicos diseñadores y ensamblados, se puede fabricar una carcasa para ambos componentes. Esta carcasa debe de no solo servir para proteger los circuitos, sino que también para facilitar el uso de ambos componentes. En particular, el diseño de la varilla programadora debe tener la geometría y forma correcta para que el médico encargado de modular la terapia, pueda hacerlo de manera intuitiva.

Para esto el desarrollo se llevará acabo con los siguientes pasos:

Tomar de medidas y reproducción de placas en entorno 3D.

Diseñar el Modelo 3D para encapsulado de estimulador, con dos terminales de salida y espacio para la batería.

Diseñar el Modelo 3D para varilla programadora, con espacio para circuitos, punta donde vaya el módulo emisor y espacio para una pantalla LCD 16×2 píxeles.

Fabricar los encapsulados en PLA impreso en 3D.

Modificar los prototipos basado en retroalimentación de los usuarios y fabricación con PETG impreso en 3D.

Objetivo 4: Investigación de un encapsulado bio-compatible

La finalidad de esta fase es preparar el estimulador para que pueda ser utilizado en pruebas de campo. Entonces hay que considerar que el estimulador es un producto que esta diseñado para ser introducido dentro de un ser vivo. Los materiales y procesos de fabricación que permiten alojar un objeto extraño dentro de un ser viviente, y que el cuerpo de este individuo no lo rechace/tenga efectos adversos no son triviales. Con esto dicho y dado que dicho planteamiento requiere otras áreas de experiencia, se tendrá que conducir entrevistas y reuniones con personal capacitado en el desarrollo de productos bio-compatibles. Todo con la finalidad de encontrar un material con el que se puede trabajar en la universidad, sea de un costo lo suficientemente bajo para justificar su compra y que permita la comunicación inalámbrica entre el estimulador y su programador inalámbrico. Para poder determinar los materiales y el proceso de fabricación a ser utilizado, se proponen los siguientes pasos:

Tener una reunión informativa con un profesor de la facultad de biomédica y posteriormente una reunión con un médico de la fundación HUMANA.

Hacer un estudio comercial para determinar la selección del material/los materiales más adecuados.

Establecer si con la maquinara y métodos de fabricación disponibles en la universidad se puede hacer una carcasa para el estimulador.

Verificar si el modelo anterior para la carcasa del estimulador puede ser fabricado de dicho material.

Objetivo 5: Afinar los sistemas que se tienen e incrementar la funcionalidad

De lo que se planteó inicialmente, el estimulador es capaz de dar un tratamiento con un amplio rango de frecuencias y PWMs. También es capaz de funcionar con una modalidad manual, en donde un imán activa un sensor de efecto hall que genera una serie de pulsos de baja amplitud que buscan evitar un ataque. También se lograron varias mejoras al circuito del estimulador, utilizando un convertidor de voltaje a corriente que reduce el error de amplitud del dispositivo. La varilla programadora cuenta con una interfaz gráfica rudimentaria y con protocolos funcionales para dos tipos de emisores y receptores. Se logro mejor recepción al cambiar de receptor a uno modelo nRF24L01. Con todo esto en consideración, se busca ratificar y validar estas mejoras y seguir implementando cambios a la programación y estructura de los circuitos para poder no solo mejorar la eficiencia energética de los componentes, sino que también reducir el costo donde se posible para obtener un dispositivo que cumpla con el objetivo de ser accesible para las personas con epilepsia farmacorresistente. Se propone hacer los siguientes cambios para generar una mejora en cada uno de los componentes. específicamente se pretende reducir el consumo energético del estimulador cuando este pueda comunicarse de manera inalámbrica. De los cálculos de consumo eléctrico [7], se tiene que en modo activo de funcionamiento la comunicación inalámbrica consume suficiente corriente como para drenar la batería del estimulador en cuestión de 1 mes. Se pretende ajustar el consumo de potencia para poder lograr que la batería dure un mínimo de 1 año. Se pretende idealmente que la batería pueda durar hasta 6+ anos. Para esto se propone lo siguiente:

Poner al sistema de comunicación inalámbrica dentro del estimulador en modo sleep hasta que una señal externa proveniente de la varilla programadora despierte el módulo.

Diseñar un modelo de una sección del nervio vago a escala (con terminaciones nerviosas representadas por cobre insulado con un material que de una resistencia parecida a los nervios cubiertos de mielina), para hacer pruebas en un entorno más realista y validar los resultados de estimulación basándose en los parámetros de funcionalidad del Pulse 102.

Mejorar la interfaz gráfica de usuario de la varilla programadora y posiblemente mover la interfaz a una plataforma móvil donde el usuario pueda mandar los parámetros desde una aplicación.

Mejorar la distribución de componentes y agregar más componentes a la placa de circuitos impresos del estimulador para mantener o disminuir su tamaño.

### Cronograma de actividades

Para el cronograma de actividades se tiene planteado que el inicio del trabajo de graduación sea para finales de abril, y que se este finalizando dicho trabajo para finales de septiembre. Este cronograma contempla todas las actividades necesarias para poder integrar la varilla programadora y el estimulador y cumplir con los objetivos planteados. Se plantea que inicialmente se planea poner a funcionar en conjunto el estimulador con la varilla programadora, verificando que el emisor y el receptor de las mismas puedan mandar la información correcta a la frecuencia correcta para permitirle al estimulador cambiar su modo de funcionamiento. Luego de hacer funcionar los componentes de manera inalámbrica, se plantea el desarrollo de un circuito impreso para la varilla programadora, así como el diseño 3D de una carcasa que pueda almacenar la varilla, así como una pequeña pantalla que le de retroalimentación al usuario/médico. Como ultima parte, luego de la integración, se desea preparar un ambiente de pruebas con la fabricación de un modelo a escala del nervio vago y el planteamiento y diseño inicial de un encapsulado compatible para el estimulador. Todo esto con la finalidad de que el la siguiente fase del proyecto se puedan empezar a recolectar datos y hacer pruebas en seres vivientes.


Figura 13: Cronograma de Actividades para Estimulador de Nervio Vago Fase III- Primer Objetivo


Figura 14: Cronograma de Actividades para Estimulador de Nervio Vago Fase III- Segundo Objetivo


Figura 15: Cronograma de Actividades para Estimulador de Nervio Vago Fase III- Tercer Objetivo

Figura 16: Cronograma de Actividades para Estimulador de Nervio Vago Fase III- Cuarto Objetivo


Figura 17: Cronograma de Actividades para Estimulador de Nervio Vago Fase III- Quinto Objetivo

Numero | Actividad
1 | Juntar componentes de fase 2
2 | Probar programación y esquemático
3 | Lograr que funcione el modulo inalámbrico con SAM21E18A
4 | Establecer comunicación entre Varilla programadora y Estimulador
5 | Verificar recepción de datos/modificación de parámetros
6 | Fabricar y Soldar PCB para Estimulador V2
7 | Diseñar PCB para varilla programadora
8 | Fabricar modelo 3D Para varilla programadora
9 | Fabricar PCB para Varilla programadora
10 | Fabricar contenedor para varilla programadora
11 | Probar funcionamiento de varilla programadora con interfaz
12 | Iniciar diseño de un modelo de cobre insulado del nervio vago
13 | Fabricar equivalente del nervio vago
14 | Funcionamiento de modelo de nervio vago
15 | Ajustar varilla programadora
16 | Investigación Compatibilidad
17 | Realizar revisiones de PCBs
18 | Realizar Modificaciones
19 | Hacer pruebas con las modificaciones
20 | Iniciar con prototipo V2
21 | Pruebas de Prototipo V2
22 | Prototipo V2 + Bioencapsulado
23 | Iniciar Prototipo Final
24 | Implementación de interfaz de programación portátil
25 | Pruebas finales con Prototipo final
26 | Trabajar en Reporte de Tesis

### Índice preliminar

Prefacio

Lista de figuras

Lista de cuadros

Resumen

Abstracto

Introducción

Antecedentes

- Tratamiento VNS de LivaNova
- LivaNova VNS Pulse 102/102R y Aspire 106
- Fase Previa
- Estimulador de Nervio Vago-Fase Previa
Desarrollo y Resultados
Alcance y Limitaciones
- Varilla Programadora para Estimulador de Nervio Vago-Fase Previa

Desarrollo y Resultados
Alcance y Limitaciones

Justificación

Objetivos

- Objetivo General
- Objetivos Específicos

Alcance

Marco Teórico

- Epilepsia
- Tipos de Convulsiones
- Tratamiento de estimulación de Nervio Vago (VNS)
- Estimulador de Nervio Vago
- Varilla programadora
- VNS Pulse 102 de LivaNova
- Modos de Operación
Operación Normal
Modo Imán
Modo de Detección y Respuesta

Metodología

Resultados

- Unificación de la varilla programadora con el estimulador de nervio vago
- SERCOM SPI
- Pruebas con el estimulador y el modulo ESP8266
- Envío de datos de la varilla programadora al estimulador mediante dos ESP8266
- Protocolo SPI utilizando el modulo SPSGRFC-868
- Desarrollo de Circuitos Impresos para la Varilla Programadora y El modulo Estimulador de Nervio Vago
- Fabricación de Circuito impreso para Varilla programadora
- Fabricación de Circuito impreso con receptor inalámbrico para modulo estimulador
- Fabricación de Versiones finales de los circuitos impresos
- Desarrolló de una interfaz física de la varilla programadora y prototipo de un encapsulado para el estimulador
- Diseño del encapsulado de la varilla programadora y su pantalla LCD
- Modelado 3d de un encapsulado para el modulo estimulador
- Fabricación del encapsulado y sus respectivas salidas utilizando técnicas FMD con PLA/PLA+

- Modelo del encapsulado utilizando PETG/ABS
- Investigación de un encapsulado bio-compatible
- Reducción de consumo de potencia con el sistema inalámbrico
- Diseño de un nervio vago a escala para pruebas de laboratorio

Conclusiones

Recomendaciones

Referencias

Anexos

Modelos y Planos

Resultados de Pruebas

Código

- Arduino (C)
- Python

Diseño de Circuitos Impresos

### Referencias

[1] LivaNova, «VNS Therapy System Epilepsy Physician’s Manual,» Bioinspiration & biomimetics, vol. 1, n.o 1, pág. 164, 2020.
[2] G. Chicago, VAGUS NERVE STIMULATION. dirección: https://epilepsychicago.org/what-is-epilepsy/treatment/vagus-nerve-stimulation/. (https://epilepsychicago.org/what-is-epilepsy/treatment/vagus-nerve-stimulation/)
[3] LivaNova, AspireSR All the benefits of previous generations of VNS Therapy. dirección: https://epilepsyswo.ca/wp-content/uploads/2019/05/AspireSRFAQ.pdf.
[4] C. 2007, Welcome to VNS Therapy. dirección: http://dynamic.cyberonics.com/depression/hcp/ForSurgeons/implanted.aspx. (http://dynamic.cyberonics.com/depression/hcp/ForSurgeons/implanted.aspx)
[5] F. 2019, Patente de Cybertronics Pulse 102. dirección: https://www.accessdata.fda.gov/cdrh_docs/pdf/p970003s207b.pdf. (https://www.accessdata.fda.gov/cdrh_docs/pdf/p970003s207b.pdf)
[6] G. A. O. Agustin, «Diseño e Implementación de un Prototipo de Estimulador del Nervio Vago para el Tratamiento de Epilepsia- Fase II,» Tesis de licenciatura, UNI-VERSIDAD DEL VALLE DE GUATEMALA, 2020.
[7] M. A. Alvarez, «Desarrollo y Validación de una Plataforma de Hardware y Software para el Programador Inalámbrico de un Neuroestimulador del Nervio Vago - Fase II,» Tesis de licenciatura, UNIVERSIDAD DEL VALLE DE GUATEMALA, 2020.
[8] V. con Epilepsia, Guía Epilepsia y Adultos. dirección: https://vivirconepilepsia.es/guia-epilepsia-y-adultos. (https://vivirconepilepsia.es/guia-epilepsia-y-adultos)
[9] HUMANA, Refractory Epilepsy. dirección: https://humanagt.org/epilepsia/.
[10] CDC Tipos de convulsiones, https://www.cdc.gov/epilepsy/spanish/basicos/convulsiones.html, (https://www.cdc.gov/epilepsy/spanish/basicos/convulsiones.html) Accessed: 2021-04-03.

[11] JHM, Refractory Epilepsy. dirección: https://www.hopkinsmedicine.org/health/conditions-and-diseases/epilepsy/refractory-epilepsy. (https://www.hopkinsmedicine.org/health/conditions-and-diseases/epilepsy/refractory-epilepsy)
[12] D. Wells, Simple Partial Seizure. dirección: https://www.healthline.com/health/simple-partial-seizure. (https://www.healthline.com/health/simple-partial-seizure)
[13] W. C. O. JAIME CARRIZOSA MOOG, «¿Qué es la epilepsia refractaria?» IATREIA, vol. 16, n.o 2, págs. 163-167, 2003.
[14] J. V. M. Virginia Meca Lallana, «Fármacos antiepilépticos,» GH CONTINUADA, vol. 8, n.o 6, págs. 332-335, 2009.
[15] G. L. A. David M Labiner, «Vagus nerve stimulation therapy in depression and epilepsy: therapeutic parameter settings,» National Library of Medicine, vol. 10, n.o 1111, 2007.

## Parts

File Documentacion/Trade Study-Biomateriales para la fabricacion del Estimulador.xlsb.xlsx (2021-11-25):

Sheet: Decisiones Previas
Decision a Ser tomada | Descripcion
Como definir el exito
Que sacrificios tienen que ser hechos
Profundidad del analisis
Detalles del estudio | Descripcion
Proposito del estudio | El proposito de este estudio es determinar de manera inicial, cual es el mejor material/ combinacion de materiales para la fabricacion del encapsulado para el estimulador de nervio vago. Todo esto basandose en la disponibilidad del material, el precio, asi como otra serie de factores para poder fabricarlo localmente
Alcance del Estudio | El estudio comprendera 5 materiales diferentes, utilizados para dispositivos medicos implantables con propositos de estimulacion nerviosa. Para cada uno de estos materiales buscaremos 3 marcas locales y 3 marcas internacionales que puedan suplirnos con el material
Descripcion del Trade Study | En este estudio se quiere validar la seleccion de material a utilizar par fabricar el encapsulado que recubre el PCB del estimulador. Se desea encontrar un material que sea biocompatible para poder colocarlo en la parte baja del cuello adentro del paciente. Que tenga las propiedades mecanicas adecuadas para poder asegurar el funcionamiento del estimulador atrave de su uso diario. Por ultimo se desea que sea lo mas ligero posible para reducir costos e incrementar el nivel de ergonomia que ste presenta frente al paciente

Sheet: Entradas y Su peso
Entrada | Peso | Descripcion
Precio | 30 | En esta categoria se desea cuantificar el precio por gramo del material a ser utilizado. Se busca que el precio sea representativo no solo del material en bruto, sino del material mas todos los procesos de manufactura necesarios para permitirnos moldear una carcaza con el mismo
Acesibilidad | 30 | Una parte fundamental de poder fabricar cualquier cosa, es saber si la materia prima esta disponible localmente. Los precios de importacion ademas de otras posibles tarifas fronterisas podrian dificultar de sobremanera el poder obtener el material. Se quiere saber que tan facil es de consegui o de mandar a traer
Facilidad de Manufactura | 15 | Para poder fabricar la carcaza basandonos en un modelo CAD, es necesario saber el metodo de fabricacion de la carcaza. Depediendo del material, se pueden utilizar tecnicas additivas o subtractivas de manufactura para darle la forma a la pieza que queremos. Si un material requiere de muchos procesos para poderlo moldear en la forma que se requiere, esto es otro factor que puede elevar la fabricacion y el costo de la misma
Propiedades Mecanicas | 10 | Dado que el dispositivo es implantable, es necesario que este tenga cierta resistencia a los impactos y pueda soportar la vida de una persona activa. Un material que sea demasiado fragil no solo pone en riesgo el estimulador, sino que tambien a la vida de la persona
Peso | 5 | Es importante reducir el impacto del implante en el cuerpo del paciente. No podemos cargar al paciente con un kg de metal a la hora de quererle implantar un dispositivo. Al reducir el peso del mismo, no solo garantizamos un mayor confort para el paciente, sino que tambien garantizamos una mejor adhesion al tejido
Biocompatibilidad | 10 | La biocompatiilidad viene en muchas formas y la manera en que se adapatan los materiales al cuerpo del paciente es muy importante. Hay que garantizar que no va exsistir una respuesta negativa por parte del cuerpo a la hora de introducir un componente con un material extrano. Se pretenderia que el material biocompatible perfecto fuera completamente esteril, y pudiera no solo introducirse en el cuerpo del paciente y que el mismo cuerpo formara tejido alrededor del mismo componente.
TOTAL | 100

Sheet: Listado de Materiales
 | Material |  | Nombre | Esfuerzo ultimo de Tension |  | Disponible localmente |  | Procesos de Manufactura disponibles | Tipo de Biocompatibilidad |  | Densidad g/cm^3
 | Ti-6Al-4V |  | 90% Titanio, 6% Aluminio 4% Vanadio | 860 Mpa |  | No* |  | Substractiva | Ideal, completamante inerte |  | 4.512
Semiconductor | SiC |  | Silicon Carbide | 240-1620 Mpa |  | No* |  |  | Intermedia, el componente de silicona puede resultar en ciertos problemas |  | 3.21
Degradable | Chitosan |  | Chitosan de Tendon | 56.5-79.3 Mpa |  | No* |  | Atravez de replicacion molecular para formar cadenas se puden hacer formas atravez de moldeo por injeccion | No es ideal, debido a que tiene una rapida degradacion |  | 0.38 g/ml
Degradable | PCL |  | Poly(ε-caprolactone) | 28-50 Mpa |  | No* |  | Metodos Aditivos, FDM | No es ideal, debido a que tiene una rapida degradacion |  | 1.2
Degradable | PHA |  | poli-4-hidroxibutirato |  |  | No* |  | Metodos Aditivos, FDM |  |  | 1.23
 |  |  |  |  | Opciones de Metales
 | Encapsulamiento |  | No tan importante |  | Zirconio |  | Bio-vidrio | Cobalto-Cromo-Mol | CoCrMo | Forma de memoria
 | Inerte |  |  |  | Al316L |  | Grado medico | PTFE | Teflon |  |  |  |  | Ti-6Al-4V |  |  |  | SiC |  | Chitosan | PCL | PHA
 | Anti-Corrosivos |  |  |  | Acero inoxidable 304 |  |  | https://bioelecmed.biomedcentral.com/articles/10.1186/s42234-020-00059-z | Carbon Nanotubes
 | Oxidacion | Bueno |  |  | Nickel-Titanio |  | Nitinol
 |  |  |  |  | Cromo-Cobalto |  | Cr-Co | Forma de memoria
 | Ti-6Al-4V |  |  |  |  |  |  |  |  |  |  |  | Chitosan
 |  |  |  |  |  |  |  |  | Recubrimientos Biocompatibles
 | Vendedor 1 |  | Vendedor 2 | Vendedor 3 |  | Vendedor 4 |  | Vendedor 5 |  |  |  |  | Vendedor 1 |  | Vendedor 2 | Vendedor 3 | Vendedor 4 |  | Vendedor 5
Nombre | Baoji Hanz Material Technology |  | Tekna | Goodfellow |  | USA Metals |  | Hangyuan Titanium |  |  |  | Nombre | biOrigins |  | GNC | FarmaListo | Aura Vitalis |  | now
Precio /g | $0.055 |  | $5.23 | $0.175 |  | $6.820 |  | $0.025 |  |  |  | Precio /g | $0.50 |  | $1.44 | $0.51 | $0.29 |  | $0.18
Pais | China |  | Canda | Alemania |  | USA |  | China |  |  |  | Pais | USA |  | Reino Unido | Mexico | Chile |  | USA
Tarifas? | Importacion |  | Importacion | $750 |  | Importacion |  | $5 |  |  |  | Tarifas?
Referencias | https://spanish.alibaba.com/product-detail/astm-b265-grade-5-ti6al4v-titanium-alloy-sheet-price-per-kg-1600170922887.html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 |  | http://www.tekna.com/spherical-powders/ti64-titanium-alloy | http://www.goodfellow.com/E/Titanium-Aluminium-Vanadium-Alloy.html |  | https://www.onlinemetals.com/en/buy/titanium-round-bar-6al-4v |  | https://www.amazon.com/Titanium-Grade-6Al-4V-Round-Material/dp/B087M5X188 |  |  |  | Referencias | https://guatemaladigital.com/Categoria/Productos+-+cuidado+de+la+piel/Chitosan+Powder+-+100g/Producto/1448837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 |  | https://guatemala.desertcart.com/products/63514016-chitosan-350-mg-90-capsules | https://www.farmalisto.com.mx/suplementos-alimenticios/8022-comprar-vita-mia-chitosan-frasco-con-60-capsulas-suplmento-alimenticio-precio-7502262362108-nutri-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 | https://www.auravitalis.cl/por-categorias/centella-chitosan/ |  | https://www.amazon.com/NOW-Chitosan-500-Chromium-Capsules/dp/B0013OSLWG
Como viene el material? | Barras |  | Polvo | Barra 10 cm & 1cm de diametro |  | Barra de 12 pulgadas |  | 1.26 pulg de radio y 9.8 puklgadas de largo |  |  |  | Como viene el material? | Polvo 100 g |  | 90 Capsulas 350 mg | 60 capsulas de .5g | 60 capsulas de .5 g |  | 240 capsulas de .5g
Tiempo estimado de Arribo | 20 dias min |  |  |  |  |  |  | 1 mes - 2 meses |  |  |  | Tiempo estimado de Arribo |  |  | 5-8 dias |  |  |  | 2 semanas
 | SiC |  |  |  |  |  |  |  |  |  |  |  | PLC
 | Vendedor 1 |  | Vendedor 2 | Vendedor 3 |  | Vendedor 4 |  | Vendedor 5 |  |  |  |  | Vendedor 1 |  | Vendedor 2 | Vendedor 3 | Vendedor 4 |  | Vendedor 5
Nombre |  |  | Industria Supply Inc | Goodfellow |  | Home Depot |  |  |  |  |  | Nombre
Precio /g | $0.01 |  | $0.01 | $4.50 |  |  |  |  |  |  |  | Precio /g
Pais |  |  | USA | Alemania |  |  |  |  |  |  |  | Pais
Tarifas? |  |  |  |  |  |  |  |  |  |  |  | Tarifas?
Referencias |  |  | https://sandblastingabrasives.com/silicon-carbides-10/black-sic-11.html | http://www.goodfellow.com/catalogue/GFCat4J.php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 |  | https://www.homedepot.com/p/ALC-25-lbs-Medium-Silicon-Carbide-40419/303890489 |  |  |  |  |  | Referencias
Como viene el material? |  |  | Bolsa de 25 LBS | Bolsa de 50 g, en Polvo |  | Bolsa de 25 lbs como Abraivo |  |  |  |  |  | Como viene el material?
Tiempo estimado de Arribo |  |  |  |  |  |  |  |  |  |  |  | Tiempo estimado de Arribo
 | PHA
 | Vendedor 1 |  | Vendedor 2 | Vendedor 3 |  | Vendedor 4 |  | Vendedor 5
Nombre
Precio
Pais
Tarifas?
Referencias
Como viene el material?
Tiempo estimado de Arribo

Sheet: Nuevo listado de materiales
Numero | Material |  | Nombre |  | Esfuerzo ultimo de Tension |  | Procesos de Manufactura disponibles | Tipo de Biocompatibilidad |  | Densidad g/cm^3
1 | Ti-6Al-4V |  | 90% Titanio, 6% Aluminio 4% Vanadio |  | 860 Mpa |  | Substractiva | Ideal, completamante inerte |  | 4.512
2 | ZrO2 |  | Dioxido de Zirconio/ Zirconia |  | 750 Mpa |  | Additiva/Substractiva | Decente, parcialmente inerte |  | 6.501
3 | SS316L |  | Acero inoxidable 316 grado 4 |  | 515 Mpa |  | Substractiva | Ideal, completamante inerte |  | 7.85
 |  |  |  |  |  |  |  |  |  |  |  |  | Ti-6Al-4V |  |  |  | ZrO2 |  | SS316L | SS304
4 | SS304 |  | Acero inoxidable con cromo y niquel |  | 720 Mpa |  | Substractiva | Ideal, completamante inerte |  | 8
5 | Nickel-Titanio |  | 60NiTi |  | 895 Mpa |  | Substractiva | Ideal, completamante inerte |  | 6.7
6 | Cromo-Cobalto |  | ASTM F75 |  | 960 Mpa |  | Substractiva | Ideal, completamante inerte |  | 8.3
7 | Cobalto-Cromo-Mol |  | ASTM F562 |  | 569 Mpa |  | Substractiva | Decente, parcialmente inerte |  | 8.43
8 | PTFE |  | Polytetrafluoroethylene |  | 20.68 Mpa |  | Aditiva/Substractiva | Decente, parcialmente inerte |  | 2.2 |  |  | Nitinol |  |  |  | ASTM F75 |  | ASTM F562 | PTFE
 |  | Ti-6Al-4V |  |  |  |  |  |  |  | ZrO2 |  |  |  |  | SS316L
 |  | Vendedor 1 |  | Vendedor 2 |  | Vendedor 3 |  |  |  | Vendedor 1 | Vendedor 2 | Vendedor 3 |  |  | Vendedor 1 | Vendedor 2 |  | Vendedor 3
 | Nombre | Baoji Hanz Material Technology |  | Tekna |  | Goodfellow |  |  | Nombre | Goodfellow | Sanno | Chemsavers |  | Nombre | Sunflex | TWMetals |  | TJYCT Steel Co.
 | Precio /g | $0.055 |  | $5.23 |  | $0.175 |  |  | Precio /g | $0.038 | $0.10 | $0.590 |  | Precio /g | $0.005 | $2.32 |  | $0.003
 | Pais | China |  | Canda |  | Alemania |  |  | Pais | Alemania | China | USA |  | Pais | India | USA |  | China
 | Tarifas? | Importacion |  | Importacion |  | $750 |  |  | Tarifas? |  |  |  |  | Tarifas?
 | Referencias | https://spanish.alibaba.com/product-detail/astm-b265-grade-5-ti6al4v-titanium-alloy-sheet-price-per-kg-1600170922887.html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 |  | http://www.tekna.com/spherical-powders/ti64-titanium-alloy |  | http://www.goodfellow.com/E/Titanium-Aluminium-Vanadium-Alloy.html |  |  | Referencias | http://www.goodfellow.com/A/Zirconium-Metal.html | https://www.amazon.com/Zirconium-Oxide-Purified-Powder-25g/dp/B00JKRA9VE | https://www.amazon.com/Zirconium-Oxide-Purified-Powder-25g/dp/B00JKRA9VE |  | Referencias | https://www.sunflexmetal.com/astm-a276-ss-316l-round-bars-suppliers-manufacturer.html | https://www.twmetals.com/w-316-316l-a-312-38397.html
 | Como viene el material? | Barras |  | Polvo |  | Barra 10 cm & 1cm de diametro |  |  | Como viene el material? | Barra de 100 cm con 1.5 mm de diametro | Polvo | Zirconium Oxide, Powder, 99%, 25g |  | Como viene el material? | Barras de Acero | Tubo de acero de 12 pulgadas de 1/8 de diametro |  | Tubos de Acero de 10 cm de grosor
 | Tiempo estimado de Arribo | 20 dias min |  | 12 dias min |  | 27 dias min |  |  | Tiempo estimado de Arribo |  |  |  |  | Tiempo estimado de Arribo
 |  | SS304 |  |  |  |  |  |  |  | Nitinol |  |  |  |  | ASTM F75
 |  | Vendedor 1 |  | Vendedor 2 |  | Vendedor 3 |  |  |  | Vendedor 1 | Vendedor 2 | Vendedor 3 |  |  | Vendedor 1 | Vendedor 2 |  | Vendedor 3
 | Nombre | MetalsDepot |  | Goodfellow |  | Sunflex |  |  | Nombre | Goodfellow | Sanno | Chemsavers |  | Nombre | Sunflex | TWMetals |  | TJYCT Steel Co.
 | Precio /g | $0.02 |  | $0.175 |  | $0.005 |  |  | Precio /g | $574.060 | $0.10 | $0.590 |  | Precio /g | $0.005 | $2.32 |  | $0.003
 | Pais | USA |  | Alemania |  | India |  |  | Pais | Alemania | China | USA |  | Pais | India | USA |  | China
 | Tarifas? |  |  | $750 |  |  |  |  | Tarifas? |  |  |  |  | Tarifas?
 | Referencias | https://www.metalsdepot.com/stainless-steel-products/stainless-plate-304 |  | http://www.goodfellow.com/E/Titanium-Aluminium-Vanadium-Alloy.html |  | https://www.sunflexmetal.com/astm-a276-ss-316l-round-bars-suppliers-manufacturer.html |  |  | Referencias | http://www.goodfellow.com/catalogue/GFCat4J.php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 | https://www.amazon.com/Zirconium-Oxide-Purified-Powder-25g/dp/B00JKRA9VE | https://www.amazon.com/Zirconium-Oxide-Purified-Powder-25g/dp/B00JKRA9VE |  | Referencias | https://www.sunflexmetal.com/astm-a276-ss-316l-round-bars-suppliers-manufacturer.html | https://www.twmetals.com/w-316-316l-a-312-38397.html
 | Como viene el material? | Plancha de .2 pulgadas de grosor de 1ftx1ft |  | Barra 10 cm & 1cm de diametro |  | Barras de Acero |  |  | Como viene el material? | Cable de 0.125mm de diametro, 0.5 m de largo | Polvo | Zirconium Oxide, Powder, 99%, 25g |  | Como viene el material? | Barras de Acero | Tubo de acero de 12 pulgadas de 1/8 de diametro |  | Tubos de Acero de 10 cm de grosor
 | Tiempo estimado de Arribo |  |  | 27 dias min |  |  |  |  | Tiempo estimado de Arribo |  |  |  |  | Tiempo estimado de Arribo
 |  | ASTM F562 |  |  |  |  |  |  |  | Polytetrafluoroethylene
 |  | Vendedor 1 |  | Vendedor 2 |  | Vendedor 3 |  |  |  | Vendedor 1 | Vendedor 2 | Vendedor 3
 | Nombre | Sunflex |  | TWMetals |  | TJYCT Steel Co. |  |  | Nombre | InGrup | Artiplast | Chemsavers
 | Precio /g | $0.005 |  | $2.32 |  | $0.003 |  |  | Precio /g | Q5.00 | Q7 | Q5.50
 | Pais | India |  | USA |  | China |  |  | Pais | Guatemala | Guatemala | USA
 | Tarifas? |  |  |  |  |  |  |  | Tarifas? | Importacion
 | Referencias | https://www.sunflexmetal.com/astm-a276-ss-316l-round-bars-suppliers-manufacturer.html |  | https://www.twmetals.com/w-316-316l-a-312-38397.html |  |  |  |  | Referencias | http://www.tekna.com/spherical-powders/ti64-titanium-alloy | https://www.amazon.com/Zirconium-Oxide-Purified-Powder-25g/dp/B00JKRA9VE | https://www.amazon.com/Zirconium-Oxide-Purified-Powder-25g/dp/B00JKRA9VE
 | Como viene el material? | Barras de Acero |  | Tubo de acero de 12 pulgadas de 1/8 de diametro |  | Tubos de Acero de 20 cm de grosor |  |  | Como viene el material? | Rollo | Metro | Encapsulado
 | Tiempo estimado de Arribo |  |  |  |  |  |  |  | Tiempo estimado de Arribo | Inmediata | Inmediata | 10 Dias

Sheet: Parametro de Biocompatibilidad
Propiedad | Descripcion
Carcinogenicidad | La habilidad de una substancia de Causar Cancer
Inmunogenicidad | Capacidad de una substancia de ser rechazada por el cuerpo/ sistema inmune
Teratogenicidad | Capacidad de una substancia de causar defectos de nacimiento
Hemacompatibilidad | Capacidad de una substancia de afectar el pH de la sangre o verse danada por los fluidos del sistema sanguineo
Metabolizable | Capacidad de una sibstancia de ser absorbida por el cuerpo luego de cumplir su funcion
Alta resistencia a la corrosion | Capacidad del material de resistir la alkalinidad de la sangre y de matener sus propiedades quimicas de funcionamiento dentro del cuerpo
Alta resistencia a la compresion | Propiedades mecanicas ideales para poder aguantar desplazamientos e impactos provocados por el movimiento del cuerpo/extremidad a donde se conecte el equipo

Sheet: Trade Study
Matriz de Decision |  |  | Ti-6Al-4V | ZrO2 | SS316L | SS304 | Nickel-Titanio | Cromo-Cobalto | Cobalto-Cromo-Mol | PTFE
Criterio | Peso % | Escala
Precio | 30 | 8= El mas barato 1= El mas caro | 5 | 4 | 6 | 7 | 1 | 3 | 2 | 8
Acesibilidad | 15 | 8= El mas facil de conseguir 1= El mas dificil de conseguir | 4 | 1 | 6 | 8 | 1 | 2 | 3 | 7
Facilidad de Manufactura | 15 | 8= El mas facil de manufacturar 1= El mas dificl de trabajar | 6 | 1 | 8 | 7 | 3 | 5 | 4 | 2
Propiedades Mecanicas | 10 | 8= El mas resitente a esfuerzos de impacto 1= El mas endeble | 6 | 5 | 2 | 4 | 7 | 8 | 3 | 1
Peso/Ergonomia | 5 | 8= El menos denso 1= El mas denso | 7 | 6 | 4 | 3 | 5 | 2 | 1 | 8
Biocompatibilidad/Bioseguridad | 25 | 8= Completamente Inerte 1= Posible toxicidad para el usuario | 8 | 7 | 4 | 2 | 3 | 6 | 5 | 1
Totales en % | 100% | 8 | 74.375 | 50.625 | 66.25 | 67.5 | 32.5 | 54.375 | 40.625 | 56.25

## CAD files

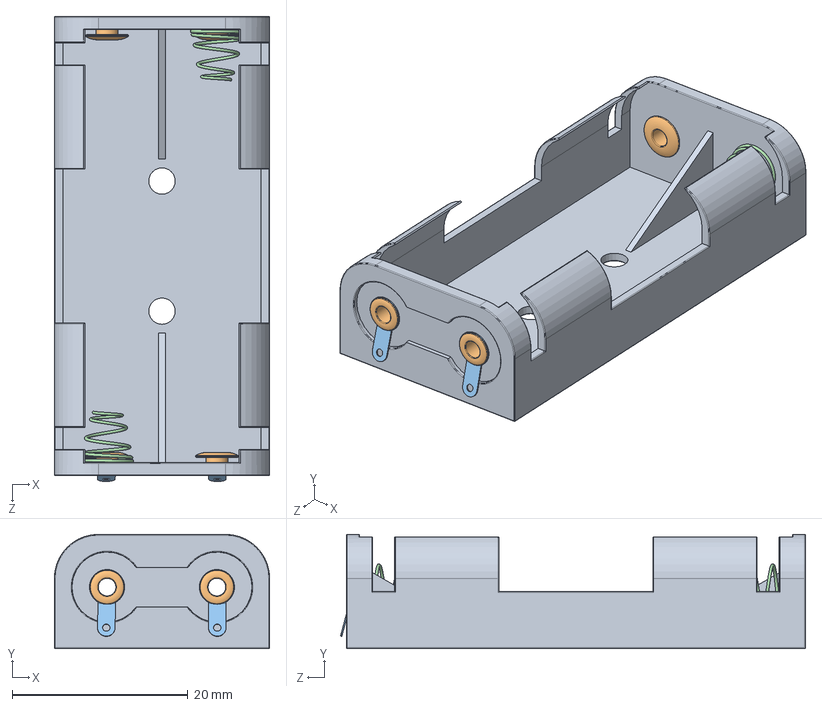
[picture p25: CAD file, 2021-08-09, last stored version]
Disenos 3D/battery-holder-20.snapshot.1/Assem1.SLDASM
24.5 x 13.0 x 52.9 mm

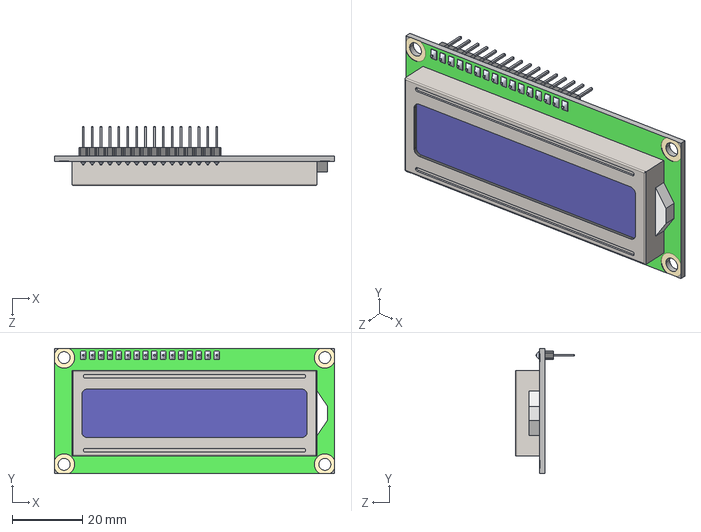
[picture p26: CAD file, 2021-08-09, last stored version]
Disenos 3D/lcd-16x2-5.snapshot.1/LCD16X2/LCD 16X2.STEP
80.0 x 35.8 x 16.9 mm

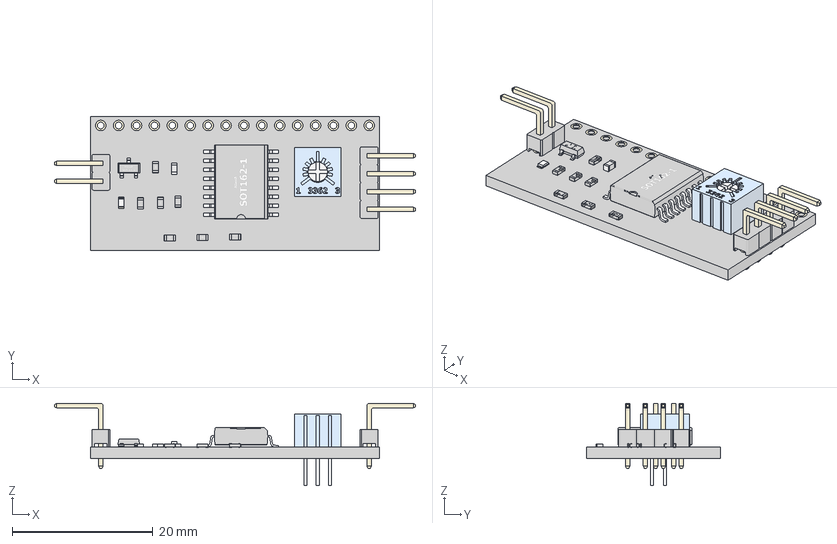
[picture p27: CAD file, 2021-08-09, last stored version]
Disenos 3D/LCDPCF8574.stp
51.2 x 19.0 x 11.7 mm
PCB
PLS-02R2
PLS-04R2
SOT162-1Package
smd-capacitor-0603
smd-resistor-0603 x 7
smd-led-0603
3362T
SOT23-3

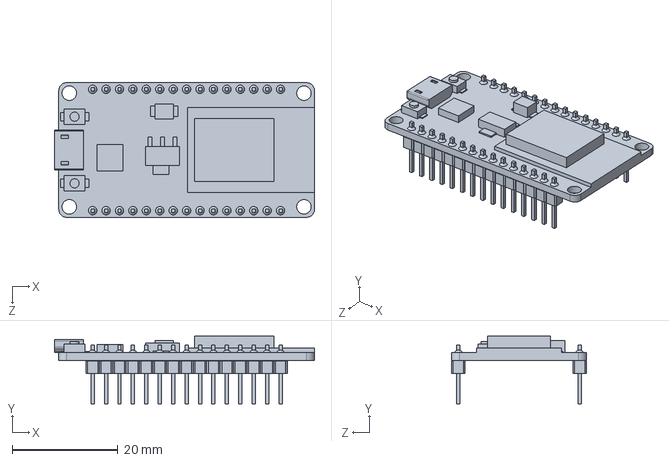
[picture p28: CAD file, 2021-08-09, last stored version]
Disenos 3D/nodemcu-esp8266-esp-12e-1.snapshot.1/nodemcu ESP8266 ESP-12E.SLDPRT
49.2 x 12.9 x 25.5 mm

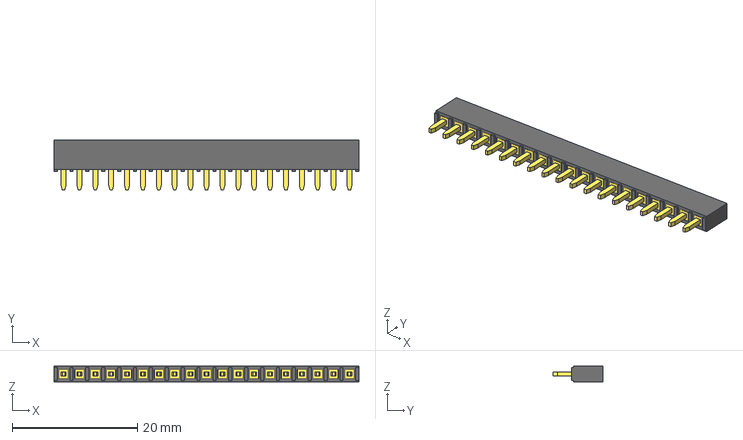
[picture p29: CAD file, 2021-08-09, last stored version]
Disenos 3D/pin-header-female-double-2-54mm-different-pin-numbers-1.snapshot.2/19-Pin Header - Female - 2.54mm.step
48.8 x 8.00 x 2.50 mm

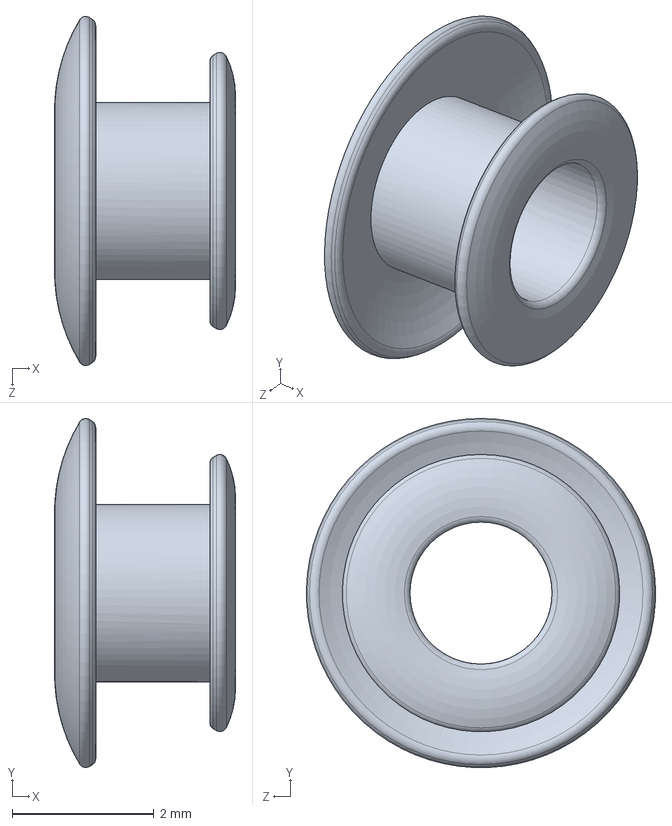
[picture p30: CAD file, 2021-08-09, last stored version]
Disenos 3D/battery-holder-20.snapshot.1/Part2.SLDPRT
2.55 x 4.92 x 4.92 mm

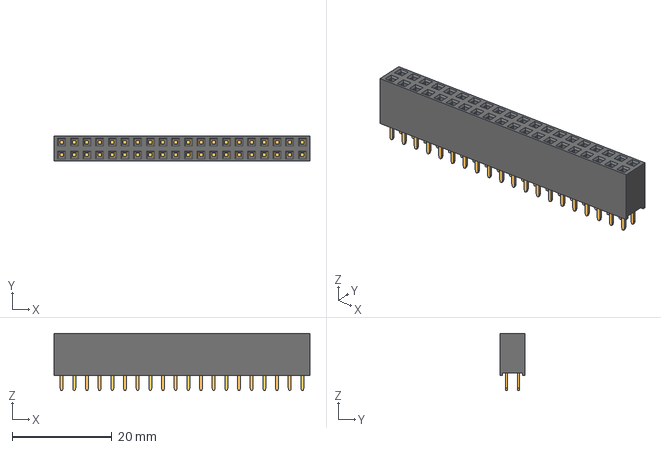
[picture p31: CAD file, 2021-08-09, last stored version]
Disenos 3D/pin-header-female-double-2-54mm-different-pin-numbers-1.snapshot.2/40-Pin Header - Female - Double - 2.54mm.step
51.3 x 5.00 x 11.5 mm

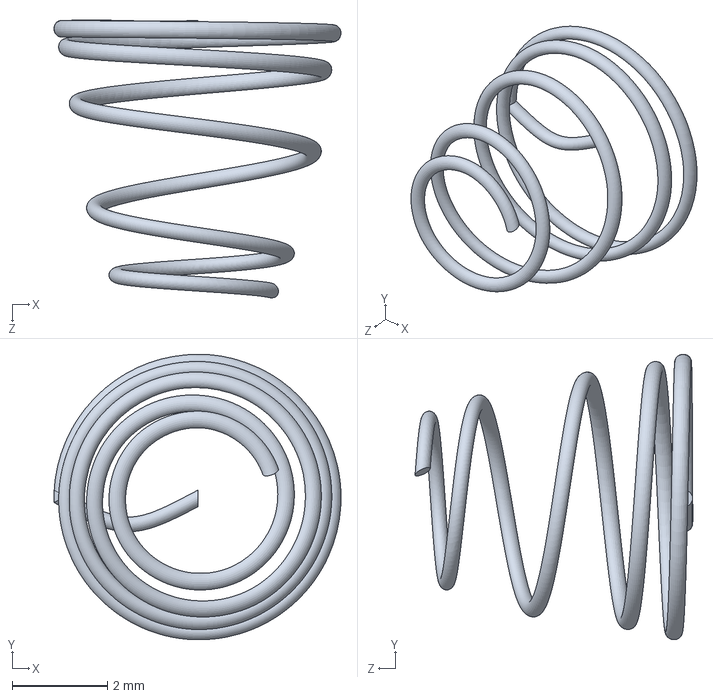
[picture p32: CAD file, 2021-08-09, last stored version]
Disenos 3D/battery-holder-20.snapshot.1/Part4.SLDPRT
6.04 x 6.00 x 5.84 mm

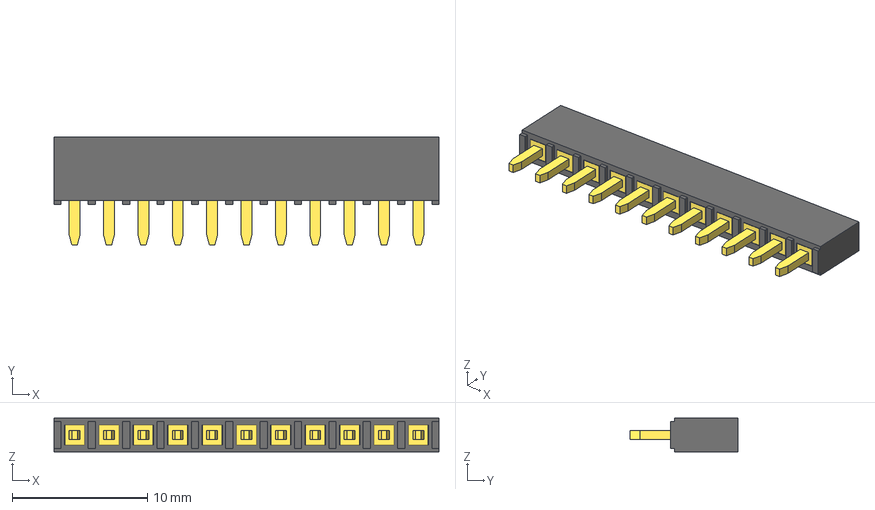
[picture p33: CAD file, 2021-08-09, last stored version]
Disenos 3D/pin-header-female-double-2-54mm-different-pin-numbers-1.snapshot.2/11-Pin Header - Female - 2.54mm.step
28.4 x 8.00 x 2.50 mm

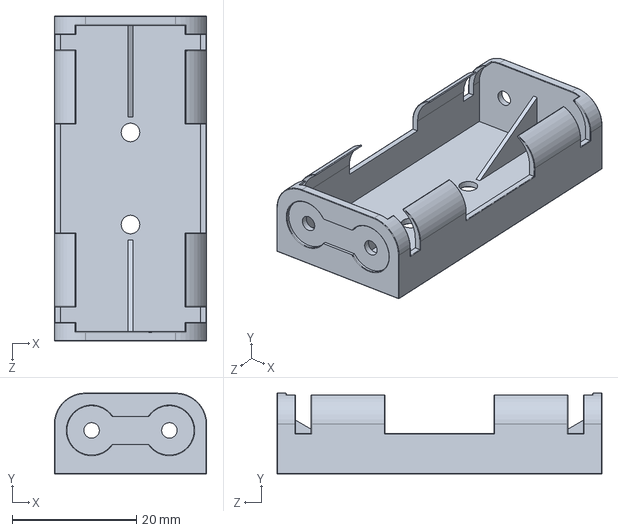
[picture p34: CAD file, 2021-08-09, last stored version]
Disenos 3D/battery-holder-20.snapshot.1/Part1.SLDPRT
24.5 x 13.0 x 52.2 mm

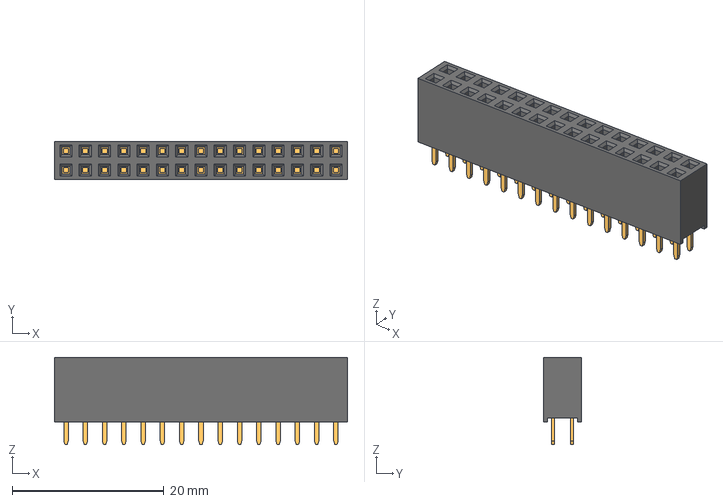
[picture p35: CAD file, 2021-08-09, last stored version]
Disenos 3D/pin-header-female-double-2-54mm-different-pin-numbers-1.snapshot.2/28-Pin Header - Female - Double - 2.54mm.step
38.6 x 5.00 x 11.5 mm

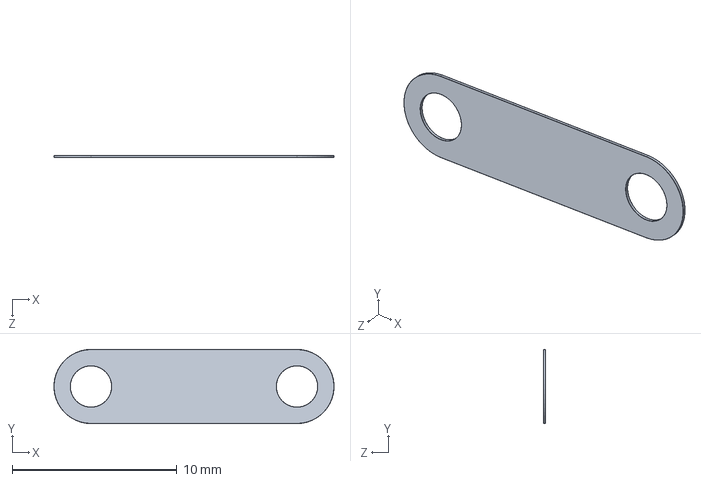
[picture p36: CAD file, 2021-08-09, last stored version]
Disenos 3D/battery-holder-20.snapshot.1/Part5.SLDPRT
17.0 x 4.50 x 0.15 mm

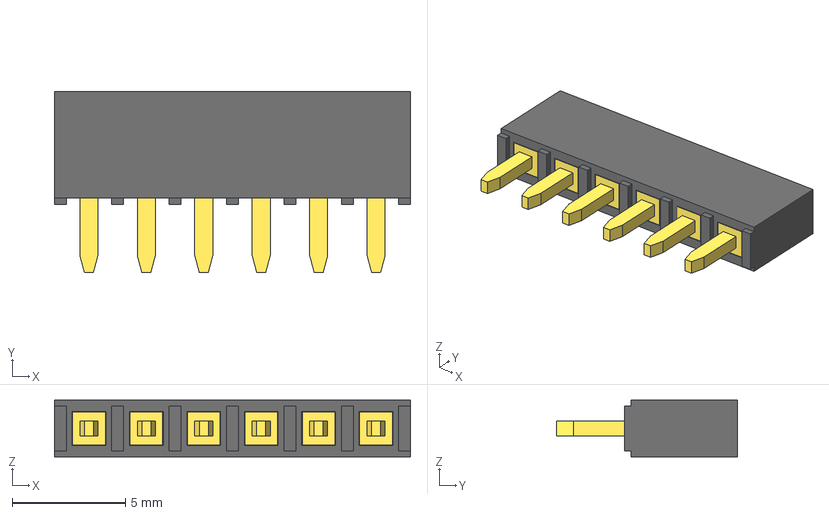
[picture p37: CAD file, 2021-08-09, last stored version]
Disenos 3D/pin-header-female-double-2-54mm-different-pin-numbers-1.snapshot.2/6-Pin Header - Female - 2.54mm.step
15.7 x 8.00 x 2.50 mm

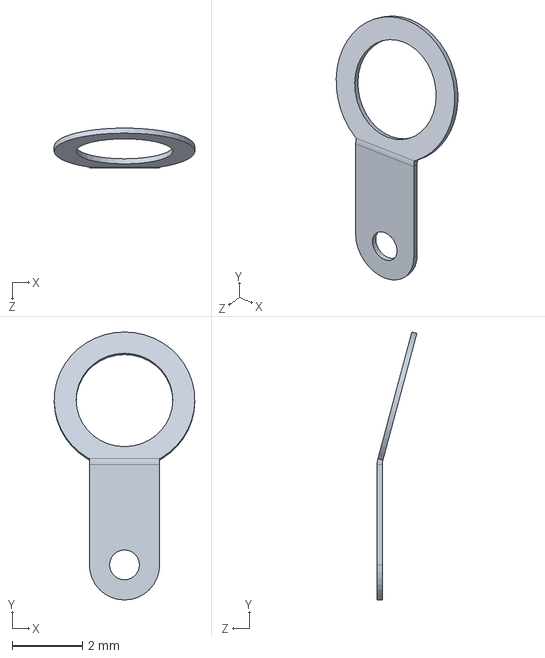
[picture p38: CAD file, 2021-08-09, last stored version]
Disenos 3D/battery-holder-20.snapshot.1/Part3.SLDPRT
4.00 x 7.62 x 1.13 mm

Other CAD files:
Disenos 3D/pin-header-female-double-2-54mm-different-pin-numbers-1.snapshot.2/10-Pin Header - Female - 2.54mm.step
Disenos 3D/pin-header-female-double-2-54mm-different-pin-numbers-1.snapshot.2/2-Pin Header - Female - 2.54mm.step
Disenos 3D/pin-header-female-double-2-54mm-different-pin-numbers-1.snapshot.2/16-Pin Header - Female - 2.54mm.step
Disenos 3D/pin-header-female-double-2-54mm-different-pin-numbers-1.snapshot.2/20-Pin Header - Female - Double - 2.54mm.step
Disenos 3D/3362T.ipt
Disenos 3D/Assembly1.iam
Disenos 3D/Base de CObre.ipt
Disenos 3D/Cubierta SUperior.ipt
Disenos 3D/Cubierta parte 1.ipt
Disenos 3D/LCDPCF8574.iam
Disenos 3D/OldVersions/Assembly1.0008.iam
Disenos 3D/OldVersions/Base de CObre.0001.ipt
Disenos 3D/OldVersions/Cubierta SUperior.0007.ipt
Disenos 3D/OldVersions/Cubierta parte 1.0005.ipt
Disenos 3D/OldVersions/Part17.0001.ipt
Disenos 3D/PCB.ipt
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

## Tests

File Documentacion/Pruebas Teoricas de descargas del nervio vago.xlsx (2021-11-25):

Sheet: Simulaciones sin distancia
 | Simulacion de Nervio
Numero de Corrida | Duty Cycle % | Tiempo de Encendido S | Frecuencia Hz | Amplitud mA | Resultado | Valor de Resistencia 1 Kohms | Valor de Resistencia 2 | Valor de Capacitor micro farads
 | 50 | 0.00013 | 7692.307692 | 0.25 |  | 33 | 10 | 10
 | 50 | 0.00013 | 7692.307692 | 1.25 |  | 33 | 10 | 10
 | 50 | 0.00013 | 7692.307692 | 3.5 |  | 33 | 10 | 10
 | 50 | 0.00025 | 4000 | 0.25 |  | 33 | 10 | 10
 | 50 | 0.00025 | 4000 | 1.25 |  | 33 | 10 | 10
 | 50 | 0.00025 | 4000 | 3.5 |  | 33 | 10 | 10
 | 50 | 0.0005 | 2000 | 0.25 |  | 33 | 10 | 10
 | 50 | 0.0005 | 2000 | 1.25 |  | 33 | 10 | 10
 | 50 | 0.0005 | 2000 | 3.5 |  | 33 | 10 | 10
 | 50 | 0.00075 | 1333.333333 | 0.25 |  | 33 | 10 | 10
 | 50 | 0.00075 | 1333.333333 | 1.25 |  | 33 | 10 | 10
 | 50 | 0.00075 | 1333.333333 | 3.5 |  | 33 | 10 | 10
 | 50 | 0.001 | 1000 | 0.25 |  | 33 | 10 | 10
 | 50 | 0.001 | 1000 | 1.25 |  | 33 | 10 | 10
 | 50 | 0.001 | 1000 | 3.5 |  | 33 | 10 | 10
 | 50 | 0.00013 | 7692.307692 | 0.25 |  | 33 | 10 | 0.1
 | 50 | 0.0005 | 2000 | 1.25 |  | 33 | 10 | 0.1
 | 50 | 0.001 | 1000 | 3.5 |  | 33 | 10 | 0.1
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

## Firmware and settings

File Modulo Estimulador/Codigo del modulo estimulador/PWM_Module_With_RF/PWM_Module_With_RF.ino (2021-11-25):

/* PWM_Module_With_RF
 * 
 * Codigo para el modulo de estimulacion VNS. Este codigo esta disenado para que un microcontrolador SAMD21E18 genere pulsos
 * PWM deacuerdo con la definicion de parametros del usuario.
 * Ademas de eso tambien adapta el modulo estimulador para funcionar con cualquier modulo tipo NRF24L01 y de esa manera recibir los parametros de programacion
 *Autores:
 * Rodrigo Jose Figueroa Hernandez - 161678  Fase III
 * Gustavo Ordoñes - 16357 Fase II
 * Ingeniería Mecatrónica/Electronica - UVG

  */
// ............................................. Librerias usadas para el modulo NRF24L01 .............................
#include <SPI.h>
#include <nRF24L01.h>
#include <RF24.h>

// ............................................. Variables de comunicacion por RF usando NRF24L01 ......................
#define CE_PIN   PORT_PA18 //
#define CSN_PIN  PORT_PA17//
RF24 radio(CE_PIN, CSN_PIN); // Instancia del módulo RF. CE = pin PA18, CSN = pin PA17
const byte addresses [][6] = {"00001", "00002"}; // Direcciones de escritura y lectura 
int contSec = 0;
uint8_t dataBus[6]; // Bus de parámetros
uint8_t dataConfOut[2]; // Bus de confirmación
uint8_t dataControl = 0; // Variable para salir del modo de lectura

// ............................................. PWM and Timer Formulas ................................................

// PWM frequency:
// freq = GCLKx_freq/(TCCx_Prescaler*(1+TOP_Value))
// => Top_Value = (GCLKx_freq/TCCx_Prescaler*freq)-1

// Timer value:
// Time = (Timer_Presc*dfactor/GCLKx_freq)*(CCx+1)
// => CCx = time*(GCLKx_freq/Timer_Presc*dfactor)-1

// Note: dfactor is a scaling factor selected in clock divider to GCLKx configuration


// ....................................... PWM and Timer Values Data Base...............................................


// Frequency configuration of the Stimulation Signal (PWM) for 30, 25, 20, 15, 10, 5, 2 and 1Hz  
const unsigned int PWM_freq[3][8] = {{1562, 1874, 2343, 3124, 4687, 9374, 23437, 46874},    // 48MHz
                                     {1041, 1249, 1562, 2082, 3124, 6249, 15624, 31249},    // 8MHz
                                     {1066, 1279, 1599, 2132, 3199, 6399, 15999, 31999}};   // 32KHz

// CCx values for 1ms, 750us, 500us, 250us and 130us respectively, for pulse 
// width or hight state in the square signal (PWM) during the Stimulation Time
const unsigned char PWM_pw[3][5] = {{47, 35, 23, 12, 6},   // 48MHz
                                    {31, 23, 16, 8, 4},    // 8MHz
                                    {32, 24, 16, 8, 4}};   // 32KHz

// Array for CCx values for 600, 300, 180, 108, 66, 60 48, 30, 21, 18, 14, 7, 2, 1s respectively, for
// On/Off time for Stimulation Signal. Clock at 32KHz
const unsigned int ON_OFF_TIME[14] = {18749, 9374, 5624, 3374, 2062, 1874, 1499, 937, 655, 562, 437, 218, 62, 30};


// ........................................ PWM and Timer Values Selection .............................................


volatile unsigned int period;         // = PWM_freq[0][3];
volatile float pulse_width;           // = period*0.25; //PWM_pw[2][0];     
volatile int ON_Time;                 // = ON_OFF_TIME[13];
volatile int OFF_Time;                // = ON_OFF_TIME[13];


// ............................... Variables for PWM, Timer and Digital Potentiometer ..................................

bool flag = 0; //Declaracion de la banderas (no es necesario cambiarlas)
byte mode = 0;
byte pulsos = 0;
bool Ramp_mode = false; 
bool go_to_sleep = false;
bool update_mode = false;
bool Hall_Sensor_Armed = false;

uint8_t amplitude;
float output_voltage = 1.75;                        // Voltage (V)
uint8_t frequency = 15;                              // Hertz (Hz)
uint16_t Stimulation_time = 1;                      // Seconds (s)
uint16_t Repose_time = 2;                          // Seconds (s)

  float magnet_output_voltage = 0.5;
uint16_t magnet_Stimulation_time = 2;

float ramp_interval;
int timer_interval;
int amplitude_max;                                  // Maximum Stimulation Amplitude (V)
int amplitude_min = 0;                              // Minimum Stimulation Amplitude (V)
 
uint16_t pot_command;
uint16_t pot_value;


// .....................................................................................................................


void setup()
{

  PM->CPUSEL.reg = PM_CPUSEL_CPUDIV(2);

//...................................... Set Input/Output Pins Mode Configuration ......................................
  
  pinMode(0, OUTPUT);                                                     // VNS Stimulation Signal Output 
  pinMode(1, INPUT_PULLUP);                                               // Input for Hall Sensor (open drain)
  PORT->Group[PORTA].DIRSET.reg = PORT_PA03;                              // Set PA03 Pin as Output (CS SPI Communication)
  PORT->Group[PORTA].OUTSET.reg = PORT_PA03;                              // Set PA03 Pin to High
  //attachInterrupt(digitalPinToInterrupt(1), Hall_Sensor, FALLING);        // Configure Falling Interrupt for Hall Sensor
  attachInterrupt(digitalPinToInterrupt(1), Hall_Sensor, RISING);          // Configure Rising Interrupt for Hall Sensor
  RF_Config(); //Funcion que configura la velocidad de tranmision y el nivel de poder para envio y recpcion de datos
  SPI.begin();                                                            // Enable SPI Communication
  
// .....................................................................................................................

//........................................Set SPI Comunication with nRF4L01............................................
  PORT->Group[PORTA].DIRSET.reg= PORT_PA14; //Inicializamos el Pin 14 como CSN (CHip Select NOT), En salida
  PORT->Group[PORTA].OUTSET.reg = PORT_PA14;                        // Set CSN Pin to HIGH
  PORT->Group[PORTA].DIRSET.reg= PORT_PA15;// Inicializamos el Pin 15 como CE(Control data transmission), En salida
  
//....................................................................................................................

  amplitude_max = output_voltage*(255/3.3)+4;
  
  switch (frequency) 
  { 
    case 1:
      period = PWM_freq[1][7];    
      break;
    case 2:
      period = PWM_freq[1][6];
      break;       
    case 5:
      period = PWM_freq[1][5];
      break;       
    case 10:
      period = PWM_freq[1][4];
      break;
    case 15:
      period = PWM_freq[1][3];
      break;
    case 20:
      period = PWM_freq[1][2];
      break;
    case 25:
      period = PWM_freq[1][1];
      break; 
    case 30:
      period = PWM_freq[1][0];
      break;                                           
    default:
      period = PWM_freq[1][7];
      break;
  }

  //pulse_width = PWM_pw[1][4];
  pulse_width = period*0.5;

  switch (Stimulation_time) 
  { 
    case 1:
      ON_Time = ON_OFF_TIME[13];    
      break;
    case 2:
      ON_Time = ON_OFF_TIME[12]; 
      break;       
    case 7:
      ON_Time = ON_OFF_TIME[11]; 
      break;       
    case 14:
      ON_Time = ON_OFF_TIME[10]; 
      break;
    case 18:
      ON_Time = ON_OFF_TIME[9]; 
      break;
    case 21:
      ON_Time = ON_OFF_TIME[8]; 
      break;
    case 30:
      ON_Time = ON_OFF_TIME[7]; 
      break; 
    case 48:
      ON_Time = ON_OFF_TIME[6]; 
      break;    
    case 60:
      ON_Time = ON_OFF_TIME[5]; 
      break;                 
    case 66:
      ON_Time = ON_OFF_TIME[4]; 
      break; 
    case 108:
      ON_Time = ON_OFF_TIME[3]; 
      break;     
    case 180:
      ON_Time = ON_OFF_TIME[2]; 
      break;
    case 300:
      ON_Time = ON_OFF_TIME[1]; 
      break;          
    case 600:
      ON_Time = ON_OFF_TIME[0]; 
      break;     
    default:
      ON_Time = ON_OFF_TIME[7];
      break;
  }


  switch (Repose_time) 
  { 
    case 1:
      OFF_Time = ON_OFF_TIME[13];    
      break;
    case 2:
      OFF_Time = ON_OFF_TIME[12]; 
      break;       
    case 7:
      OFF_Time = ON_OFF_TIME[11]; 
      break;       
    case 14:
      OFF_Time = ON_OFF_TIME[10]; 
      break;
    case 18:
      OFF_Time = ON_OFF_TIME[9]; 
      break;
    case 21:
      OFF_Time = ON_OFF_TIME[8]; 
      break;
    case 30:
      OFF_Time = ON_OFF_TIME[7]; 
      break; 
    case 48:
      OFF_Time = ON_OFF_TIME[6]; 
      break;    
    case 60:
      OFF_Time = ON_OFF_TIME[5]; 
      break;                 
    case 66:
      OFF_Time = ON_OFF_TIME[4]; 
      break; 
    case 108:
      OFF_Time = ON_OFF_TIME[3]; 
      break;     
    case 180:
      OFF_Time = ON_OFF_TIME[2]; 
      break;
    case 300:
      OFF_Time = ON_OFF_TIME[1]; 
      break;          
    case 600:
      OFF_Time = ON_OFF_TIME[0]; 
      break;     
    default:
      OFF_Time = ON_OFF_TIME[0];
      break;
  }

  if (frequency >= 10) Ramp_mode = true; 
  else Ramp_mode = false;  

  
//...................................... Configurate PWM (Stimulation signal) ..........................................

  PWM_Config();
  Enable_PWM_Interrupts();  
  
// ......................... CONFIGURAR TIEMPO DE ACTUALIZACIÓN DE LA RAMPA ............................................

if (Ramp_mode == true)
{
  // CCx = (time*(8MHz/1024))-1
  // 1/time = (amplitude_max-1)/2000ms   
   
  amplitude = amplitude_min;                      // Ramp-up Starts in Amplitude = 1
  ramp_interval = (amplitude_max-1)/2;            // (98-1)/2s = 48.5Hz => 20.62ms
  timer_interval = (7812.5/ramp_interval)-1;      // (7812.5/ramp_interval)-1;     // (46,875.0/48.5)-1 = 965.49 => 965 

  Timer2_Config();                                // Configurate Timer for Ramp Amplitude Refresh
  Timer2_Interrupts();                            // Enable Ramp Amplitude Refresh
  Timer2_Start();                                 // Start Timer for Ramp Amplitude Refresh
}
else
{
  amplitude = amplitude_max;
}

//...................................... Configurar Timer (ON/OFF Time) ................................................

  Timer_Config();           
  Timer_Start();    

// .....................................................................................................................
  
  flag=1;
// .....................................................................................................................

//SPIClass SPI1 (&sercom1, 12, 13, 11, SPI_PAD_0_SCK_1, SERCOM_RX_PAD_3);

}


// .....................................................................................................................


void loop() 
{
//........................................Funcion de recepcion de parametros............................................
  RF_Begin();
//.....................................................................................................................
  if(update_mode)
  {
    next_mode();
    update_mode = false;  
  }

  if(flag)
  {
    setResistance(amplitude);     
    flag = false;
  }

  if(go_to_sleep)
  {
    go_to_sleep = false;
    SAMD21_Sleep();    
  }
  
}


// ............................. HALL Sensor Activation for On Demand Mode .............................................


void Hall_Sensor()
{

  mode = 0;
  flag = 0;
  pulsos = 0;
  go_to_sleep = false;
  
  if(Ramp_mode) amplitude = amplitude_min;
  else amplitude = amplitude_max;

  flag = true;
  update_mode = true;
  
}

// ............................. TIMER DE ACTUALIZACIÓN DE AMPLITUD DE LA RAMPA ........................................


void TCC0_Handler()
{

  if(mode==2)                                 // ¿Intevalo de Estimulación?
  {
    pulsos++;                                 // Contar pulsos realizados
    
    if(pulsos==frequency)                     // ¿# de pulsos coinciden con la frecuencia configurada?
    {
      pulsos=0;                               // Reiniciar contador de pulsos
      if(Ramp_mode == true) amplitude--;      // Disminuir amplitud para entrar en rampa de bajada
      flag=1;                                 // Actualizar amplitud del poteciometro
    } 
     
  }

  TCC0->INTFLAG.bit.MC0 = 1;                  // Clear interrupt flag
  
}


// ............................. TIMER PARA GENERAR SEÑAL PWM DE ESTIMULACIÓN ..........................................


void TCC1_Handler()
{

  if(mode==1) amplitude++;              // ¿Rampa de subida? -> Incrementar Amplitud 
  else if(mode==3) amplitude--;         // ¿Rampa de bajada? -> Decrementar Amplitud

  if(amplitude > amplitude_max) amplitude = amplitude_max;  
  if(amplitude < amplitude_min) amplitude = amplitude_min;
  
  flag = 1;
  TCC1->INTFLAG.bit.MC0 = 1;            
  
}


// .....................................................................................................................


void setResistance(int percent)
{
   
  pot_command = 0x0011;                                             // Write Command to Potentiometer
  pot_value = (pot_command << 8) | percent;                         // Add Potentiometer Value to Write Command

  PORT->Group[PORTA].OUTCLR.reg = PORT_PA03;                        // Set Potentiometer CS Pin to Low
  delayMicroseconds(50);                                            // Delay
  
  SPI.beginTransaction(SPISettings(1000000, MSBFIRST, SPI_MODE0));  // Begin SPI Transaction  
  SPI.transfer16(pot_value);                                        // Write New Value to Potentiometer
  SPI.endTransaction();                                             // End SPI Transaction
  
  delayMicroseconds(50);                                            // Delay
  PORT->Group[PORTA].OUTSET.reg = PORT_PA03;                        // Set Potentiometer CS Pin to High

}


// .....................................................................................................................


void TC5_Handler (void) 
{

  update_mode = true;
  TC5->COUNT16.INTFLAG.bit.MC0 = 1;                     // Clear interrupt flag  
  
}


// .....................................................................................................................


void next_mode(void)
{
  
  if(Ramp_mode)                                         // Ramp Mode On?
  {                                                     // Ramp Mode On (Freq. >= 10):
    mode++;                                             // Use Sequence: Ramp Up -> On Time -> Ramp Down -> Off Time
    if(mode>=5) mode=1;                                 // Reset Stimultation Sequence    
  }
  else                                                  
  {                                                     // Ramp Mode Off (Freq. < 10):
    if(mode==2) mode = 4;                               // Use Sequence: On Time -> Off Time
    else mode = 2;                                      // Reset Stimultation Sequence 
  } 

  
  if(mode == 1)                                         // Ramp Up Interval Active?
  {    
    Timer_Disable();                                    // Stop Timer to change to Ramp Up Time (2s)
    TC5->COUNT16.CC[0].reg = (uint16_t) 62;             // Set TC5 value with Ramp Up Time (2s)   
    PWM_Start();                                        // Start PWM  (Stimulation Signal)
    Timer_Start();                                      // Enable Timer again    
    Timer2_Start();                                     // Update Up Ramp Amplitude Interval     
  }
  else if(mode == 2)                                    // On Time Interval Active?
  {
    Timer2_Stop();                                      // Stop Update of Ramp Amplitude 
    pulsos=0;                                           // Reset Stimulation Pulses Count
    Timer_Disable();                                    // Stop Timer to change to ON time value       
    TC5->COUNT16.CC[0].reg = (uint16_t) ON_Time;        // Set TC5 value with ON Time (Stimulation)    
    if(Ramp_mode == false) PWM_Start();                 // Enable PWM 
    Timer_Start();                                      // Enable Timer again    
  } 
  else if(mode == 3)                                    // Down Up Interval Active?
  {    
    Timer_Disable();                                    // Stop Timer to change to Ramp Down Time
    TC5->COUNT16.CC[0].reg = (uint16_t) 62;             // Set TC5 value with Ramp Down Time    
    Timer_Start();                                      // Enable Timer again     
    Timer2_Start();                                     // Update Down Ramp Amplitude                  
  }
  else if(mode == 4)                                    // Off Time Interval Active?
  {
    Timer2_Stop();                                      // Stop Update of Ramp Amplitude   
    PWM_Stop();                                         // Disable PWM     
    Timer_Disable();                                    // Stop Timer to change to OFF Time Value
    TC5->COUNT16.CC[0].reg = (uint16_t) OFF_Time;       // Set TC5 value with OFF Time (Repose)    
    Timer_Start();                                      // Enable Timer again        
    //go_to_sleep = true;                                 // Enter in Standy Mode to Save Energy
  }
    
}


void PWM_Config()
{

  PM->APBCMASK.reg |= PM_APBCMASK_TCC0;
  //GCLK_GENCTRL_RUNSTDBY |             // Set GCLK4 to run in standby mode 


  // Enable and configure the Generic CLK Generator (GCLK)
  GCLK->GENCTRL.reg = GCLK_GENCTRL_IDC |                  // Improve duty cycle 
                      GCLK_GENCTRL_GENEN |                // Enable GCLK
                      GCLK_GENCTRL_SRC_OSC8M |            // OSC32K | OSC8M | DFLL48M |   // Set the 8MHz as Clock Source
                      GCLK_GENCTRL_ID(4);                 // Select GCLK4 as ID 
  while (GCLK->STATUS.bit.SYNCBUSY);                      // Wait for synchronization


  // Select clock divider to GCLK4
  GCLK->GENDIV.reg = GCLK_GENDIV_DIV(1) |                 // Divide 8MHz by 1 
                     GCLK_GENDIV_ID(4);                   // Apply it to GCLK4    
  while (GCLK->STATUS.bit.SYNCBUSY);                      // Wait for synchronization

  
  // Enable GCLK4 and connect it to TCC0 and TCC1
  GCLK->CLKCTRL.reg = GCLK_CLKCTRL_CLKEN |                // Enable Generic Clock 
                      GCLK_CLKCTRL_GEN_GCLK4 |            // Select GCLK4
                      GCLK_CLKCTRL_ID_TCC0_TCC1;          // Feed CLK4 to TCC0 and TCC1
  while (GCLK->STATUS.bit.SYNCBUSY);                      // Wait for synchronization


  TCC0->CTRLA.reg |= TCC_CTRLA_PRESCALER_DIV256;          // Divide counter by 1 (This is N)
  TCC0->CTRLA.reg |= TC_CTRLA_MODE_COUNT16;               // Set Timer counter Mode to 16 bits
  TCC0->WAVE.reg = TCC_WAVE_WAVEGEN_NPWM;                 // Select NPWM (Single-slope): count up to PER, match on CC[n]
  while (TCC0->SYNCBUSY.bit.WAVE);                        // Wait for synchronization

  TCC0->PER.reg = period;                                 // Set the period (TOP) for rate or frequency of PWM signal
  while (TCC0->SYNCBUSY.bit.PER);                         // Wait for synchronization

  // Set duty cycle where n for CC[n] is n = x % 4 and x is form WO[x]
  TCC0->CC[0].reg = pulse_width;                          // Set PWM signal to 50% of duty cicle 
  while (TCC0->SYNCBUSY.bit.CC0);                         // Wait for synchronization

  // Configure PA08 (D0 in Trinket) to be output
  PORT->Group[PORTA].DIRSET.reg = PORT_PA08;              // Set pin as output
  PORT->Group[PORTA].OUTCLR.reg = PORT_PA08;              // Set pin to low
  PORT->Group[PORTA].PINCFG[8].reg |= PORT_PINCFG_PMUXEN; // Enable the port multiplexer for PA08

  // Connet TCC1 timer to PA08. Function F is TCC1/WO[2] for PA08. Function E is TCC0/WO[0]
  // Odd pin num (2*n+1): use PMUXO
  // Even pin num (2*n): use PMUXE
  PORT->Group[PORTA].PMUX[4].reg = PORT_PMUX_PMUXE_E;
  
}


// .....................................................................................................................


void Enable_PWM_Interrupts(void)
{
  // Configure interrupt request
  NVIC_DisableIRQ(TCC0_IRQn);                           // Deshabilitar interrupciones
  NVIC_ClearPendingIRQ(TCC0_IRQn);                      // Limpiar banderas de interrupción
  NVIC_SetPriority(TCC0_IRQn, 0);                       // Nivel de prioridad de la interrupción
  NVIC_EnableIRQ(TCC0_IRQn);                            // Habilitar interrupciones
  
  TCC0->INTENSET.bit.MC0 = 1;                           // Enable TC5 Overflow Interrupt Request (OVF)
  while(TCC0->STATUS.reg & TC_STATUS_SYNCBUSY); 
}


// .....................................................................................................................


void PWM_Start()
{ 
  TCC0->CTRLA.reg |= (TCC_CTRLA_ENABLE);                // Enable TCC1 (Start PWM)
  while (TCC0->SYNCBUSY.bit.ENABLE);                    // Wait for synchronization     
}


// .....................................................................................................................


void PWM_Stop()
{
  TCC0->CTRLA.reg &= (~TCC_CTRLA_ENABLE);               // Disable TCC1 (Stop PWM)
  while (TCC0->SYNCBUSY.bit.ENABLE);                    // Wait for synchronization
}


// .....................................................................................................................
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

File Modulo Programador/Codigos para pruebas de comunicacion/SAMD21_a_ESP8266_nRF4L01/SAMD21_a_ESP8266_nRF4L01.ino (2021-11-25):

//ESP Mandando datos y esperando mensaje de confirmacion
/************************************************************************
   Titulo: Prueba de Emision y Recepcion de ESP8266 y SAMD21 con nRF4L01
   Receptor SAMD21
   Fecha: 29/06/21
   Autor: Rodrigo Figueroa
   Version: 1.0
 ***********************************************************************/
#include <SPI.h>
#include <nRF24L01.h>
#include <RF24.h>
/**********************************************************
   Inicializamos las variables
 *******************************************************/
//RF24 radio(0, 1); // CE, CSN //Trinket Receptor, ESP Emisor
//RF24 radio(9, 10); // CE, CSN Arduino
RF24 radio(2, 0); // CE= D3, CSN= D4 //Trinket Receptor, ESP8266 Emisor
//RF24 radio(4, 5); // CE= D3, CSN= D4 //Trinket Receptor, ESP8266 Emisor
bool leido = false;
int prueba = 1;
bool confirmacion1 = false;
bool confirmacion2 = false;
bool confirmacion3 = false;
int textint = 0;
char dataBus[7]; // Bus de parámetros
/**************************************************************************************************
   Inicializamos tanto la comunicacion Serial como la comunicacion SPI usando la libreria RadioHead
 **************************************************************************************************/
const byte address[6] = "00001";
const byte address2[6] = "00002";
void setup() {
  Serial.begin(115200);
  radio.begin();
    radio.openReadingPipe(0, address);   //Setting the address at which we will receive the data
    radio.openWritingPipe(address2); //Setting the address where we will send the data
  radio.setPALevel(RF24_PA_MIN);       //You can set this as minimum or maximum depending on the distance between the transmitter and receiver.
  radio.setChannel(108); 
  //radio.setDataRate( RF24_250KBPS );
  radio.startListening();              //This sets the module as receiver
  confirmacion1 = false;
  confirmacion2 = false;
  confirmacion3 = false;
}
/**********************************************************
   Iniciamos con el Loop
 *******************************************************/
void loop()
{
  /**********************************************************
     Le Decimos que mande un mensaje inicial para comenzar
     la comunicacion, luego que espere hasta recibir el mensaje
     de confirmacion de parametros para poder enviar los parametros
     correspondientes
   *******************************************************/
  switch (prueba) {
    /////////////////////////////////////////////////////////////////////////////////////
    case 1: {
        if (radio.available())              //Looking for the data.
        {
          char text[4] = "";                 //Saving the incoming data
          radio.read(&text, sizeof(text));    //Reading the data
          Serial.println("El Dice:");
          Serial.println(text);
          leido = true;
          delay(20);
        }
        //if(leido == true){
        radio.stopListening();
        Serial.println("Yo digo:");
        const char text2[] = "abcdefg";
        Serial.println(text2);
        radio.write(&text2, sizeof(text2));
        delay(20);
        radio.startListening();
        break;
      }
    //////////////////////////////////////////////////////////////////////////////////////
    case 2: {
        while (confirmacion1 == false) {
          radio.startListening();
          if (radio.available())              //Looking for the data.
          {
            char text[2] = "";                 //Saving the incoming data
            radio.read(&text, sizeof(text));    //Reading the data
            Serial.println("Tu Dices:");
            Serial.println(text);
            if (strcmp(text, "1") == 0) {
              confirmacion1 = true;
              Serial.println("Confirmacion de Dato 1 Aceptada");
            }
            delay(20);
          }
          radio.stopListening();
          const char text2[] = "2";
          Serial.println("Yo digo:");
          Serial.println(text2);
          radio.write(&text2, sizeof(text2));
          delay(20);
        }
        while (confirmacion1 == true && confirmacion2 == false) {
          radio.startListening();
          char text3[1] = "";                 //Saving the incoming data
          radio.read(&text3, sizeof(text3));    //Reading the data
          Serial.println("Tu Dices:");
          Serial.println(text3);
          if (strcmp(text3, "3") == 0) {
            confirmacion2 = true;
            Serial.println("Confirmacion de Dato 2 Aceptada");
          }
          delay(20);
        }
        radio.startListening();
      }
    //////////////////////////////////////////////
    case 3: {
        radio.stopListening();
        const char text3[] = "abc";
        Serial.println(text3);
        radio.write(&text3, sizeof(text3));                  //Sending the message to receiver
        delay(20);
        break;
        //        const char text2[] = "abc";
        //        Serial.println(text2);
        //        radio.write(&text2, sizeof(text2));
        //        delay(20);
        //        radio.startListening();
        //        if (radio.available())              //Looking for the data.
        //        {
        //          char text[1] = "";                 //Saving the incoming data
        //          radio.read(&text, sizeof(text));    //Reading the data
        //          //textint = int(float(text));
        //          Serial.println(text);
        //        }
        //        delay(5);

      }
    ////////////////////////////////////////////////////////
    case 4: {
        if (radio.available())              //Looking for the data.
        {
          char text[2] = "";                 //Saving the incoming data
          radio.read(&text, sizeof(text));    //Reading the data
          //textint = int(float(text));
          Serial.println(text);
        }
        delay(5);
        break;
      }
    ///////////////////////////////////////////////////////////////////
    case 5: {
        radio.startListening(); // Módulo RF como receptor
        if (radio.available()) // Si hay datos en el pipe
        {
          Serial.println("Si hay datos");
          radio.read(&dataBus, sizeof(dataBus)); // Leer y almacenar en dataBus
          Serial.println(dataBus[0]);
          Serial.println(dataBus[1]);
          Serial.println(dataBus[2]);
          Serial.println(dataBus[3]);
          Serial.println(dataBus[4]);
          Serial.println(dataBus[5]);
          //          if (dataBus[5] == 1) { // Si el bit 5 de dataBus es 1 (recepción confirmada)
          //            dataControl = 1; // Ya no se quiere leer
          //            contSec++;
          //          }
        }
        delay(5);
        int modo = dataBus[0];
        int ancho = dataBus[1];
        int tiempo = dataBus[2];
        int freq = dataBus[3];
        int sleep = dataBus[4];
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

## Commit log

2021-03-30 Se agrega un folder al repositorio
    Se crea un folder de documento y uno para las imagenes utilizadas en el protocolo
2021-03-30 Se crea Folder de Documentos Dentro del Repositorio
2021-03-31 Movimiento de los Folders
    Se mueven los folders al sub folder 'Rodrigo Figueroa' Como fue indicado por Luis
2021-04-01 Se agregan mas imagenes para ser usadas en el protocolo
2021-08-09 Se suben todos los archivos
    Se suben todos los archivos trabajados desde Mayo 2021-Agosto 2021 Debido a problemas con el repositorio y que GitHub indica que hay archivos que son mayores a 100 Mb (que no los hay) Por lo tanto se estara subiendo manualmente los documentos necesarios para asegurarse que haya un back up
    [10-Pin Header - Female - 2.54mm.step, 10-Pin Header - Female - Double - 2.54mm.step, 11-Pin Header - Female - 2.54mm.step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]
2021-11-24 Edicion del Archivo Read Me
    Se actualiza el archivo Read Me del Github para incluir toda la informacion de los contenidos del mismo ademas de todo el material relevante de cada carpeta. Se decidio incluir toda la informacion pertinente directamente en este Read Me, mas que agregar un Read Me nuevo en cada carpeta por miedo a tener problemas de compilacion en Github
2021-11-24 Mas cambios detallados al Read Me
    Se dan instrucciones con mayor claridad y una mejor descripcion de los contenidos de cada folder
2021-11-24 Voy a tener que borrar todos los archivos
    Se van a borrar para dejarlos ordenados como parte de la entrega final
2021-11-24 Se siguen borrando alrchivos
    [10-Pin Header - Female - 2.54mm.step, 10-Pin Header - Female - Double - 2.54mm.step, 11-Pin Header - Female - 2.54mm.step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]
2021-11-25 Codigos del Modulo Estimulador
    Se agregan los codigos del Modulo estimulador, el codigo principal y los cdigos utilizados para diagnosticos y pruebas
    [Pruebas Teoricas de descargas del nervio vago.xlsx]
2021-11-25 Archivos de Codigo y link del Drive
    Se suben todos los codigos utilizados para la varilla programadora
2021-11-25 Documentacion
    Se agrega la Documentacion Correspondiente
    [Pruebas Teoricas de descargas del nervio vago.xlsx, Trade Study-Biomateriales para la fabricacion del Estimulador.xlsb.xlsx]
2021-11-26 Limpiando el repositorio
2021-11-27 Se comentan los contenidos de cada folder
    Se agrega una descripcion mas detallada de cada archivo en los folders
2021-11-27 Actualizacion varilla programadora
    Se actualizan las descripciones de codigo de la varilla programadora
2021-11-30 Sigo mejorando el readme
    Luego de leer la retroalimentacion voy a colocar algunas imagenes
2022-04-17 Se crea archivo read me que detalla contenidos
    Detalla los contenidos del repositorio hasta la fecha 4/16/22
2022-04-17 Se sube archivo PDF con defensa de Terna
